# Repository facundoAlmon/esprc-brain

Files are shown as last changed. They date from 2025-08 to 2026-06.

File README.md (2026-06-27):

<div align="right">
<span>Español | <a href="README.en.md">English</a></span>
</div>

# 🚗 ESP-RC Brain: El Cerebro de Código Abierto para tu Coche RC

¡Te damos la bienvenida al repositorio de ESP-RC Brain! Este proyecto es el cerebro de un coche a radiocontrol inteligente, construido sobre un potente microcontrolador ESP32. Aquí encontrarás todo lo necesario para dar vida a tu propio vehículo: el firmware, los modelos 3D y una increíble aplicación web para que tomes el control desde cualquier navegador.

Este no es solo un coche a RC, es una plataforma abierta para que puedas experimentar, aprender y, sobre todo, ¡divertirte a lo grande!

¿Querés ver lo que ve el coche? Este proyecto tiene un módulo de cámara FPV complementario: **[esprc-cam](https://github.com/facundoAlmon/esprc-cam)**, un firmware para el módulo AI-Thinker ESP32-CAM que transmite video en vivo directamente a la webapp del brain.

## 🎬 Galería del Proyecto

### Videos

<p align="center">
<a href="https://www.youtube.com/watch?v=_Qa1ab6sNVU">
Demostracion de funcionamiento y control
</a>
<a href="https://www.youtube.com/watch?v=7CDSC2cwirc">
Control del auto con joystick de PS4
</a>
</p>

### Imágenes

<p align="center">
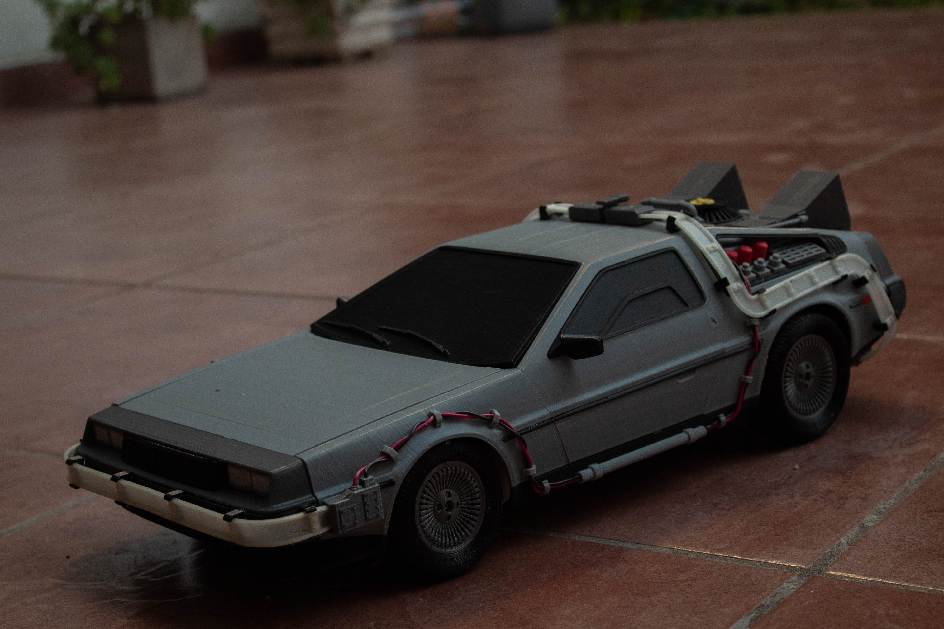
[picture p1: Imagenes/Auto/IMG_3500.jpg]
  
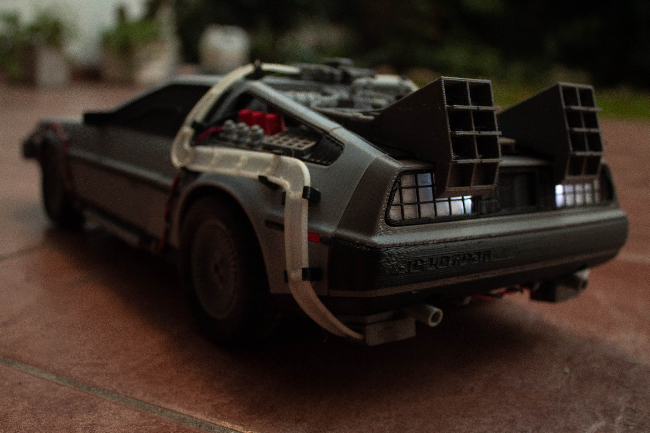
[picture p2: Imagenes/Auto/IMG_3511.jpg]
  
</p>
<p align="center">
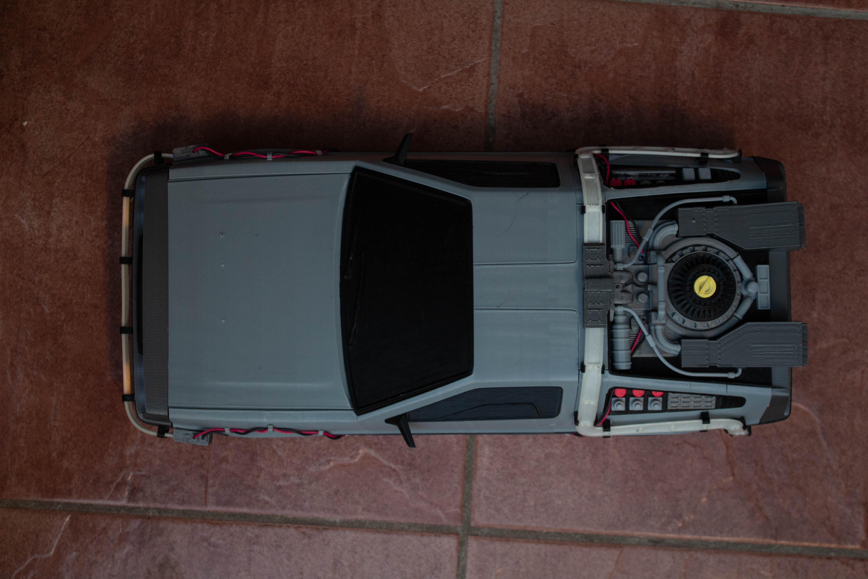
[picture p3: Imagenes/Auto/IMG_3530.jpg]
  
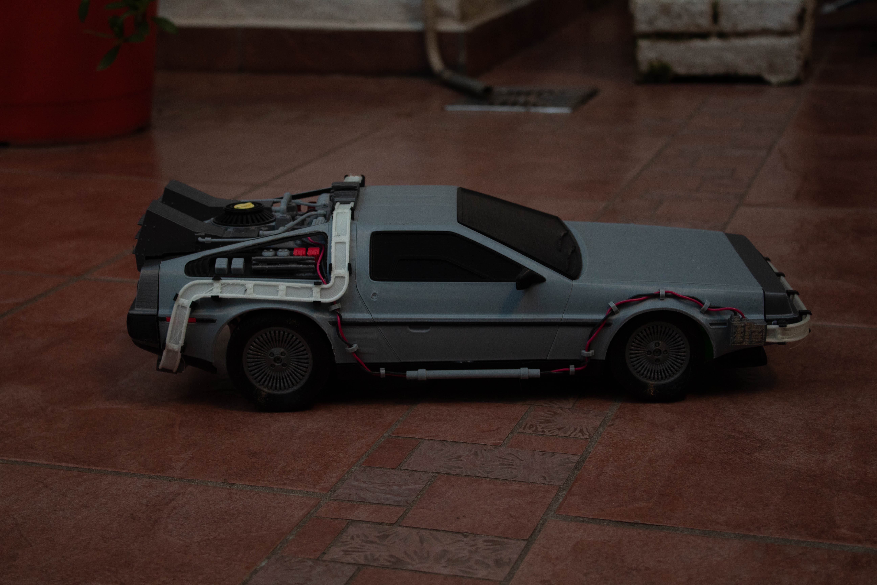
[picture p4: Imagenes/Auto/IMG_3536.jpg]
  
</p>
<p align="center">
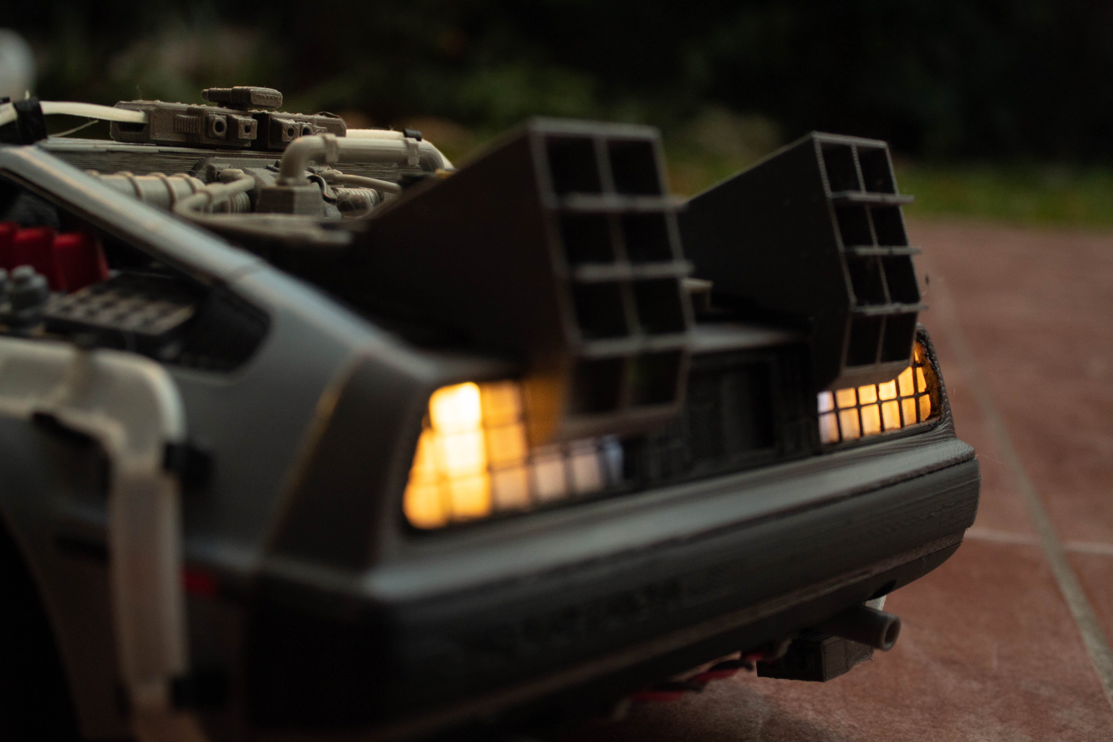
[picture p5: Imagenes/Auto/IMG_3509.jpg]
  
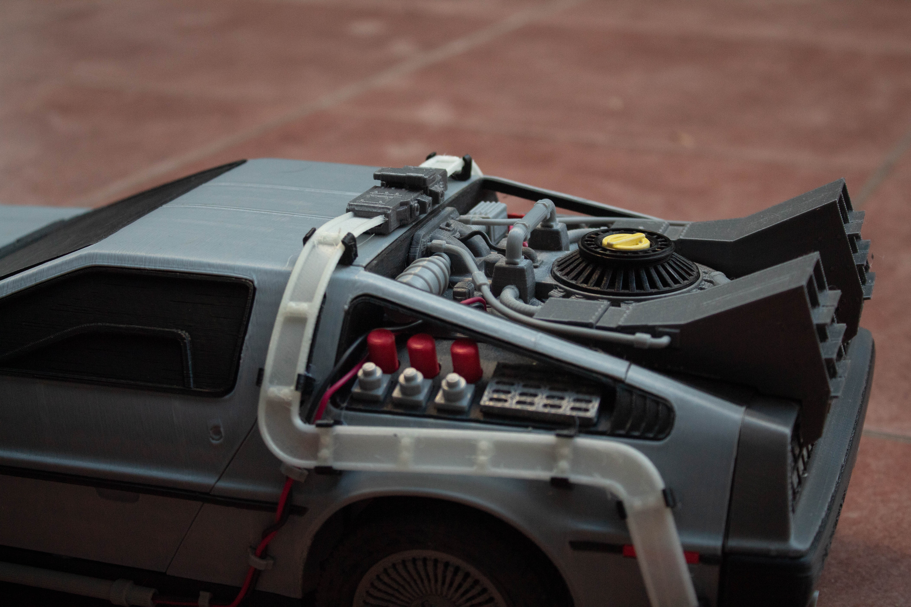
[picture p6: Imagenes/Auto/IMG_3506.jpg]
  
</p>
<p align="center">
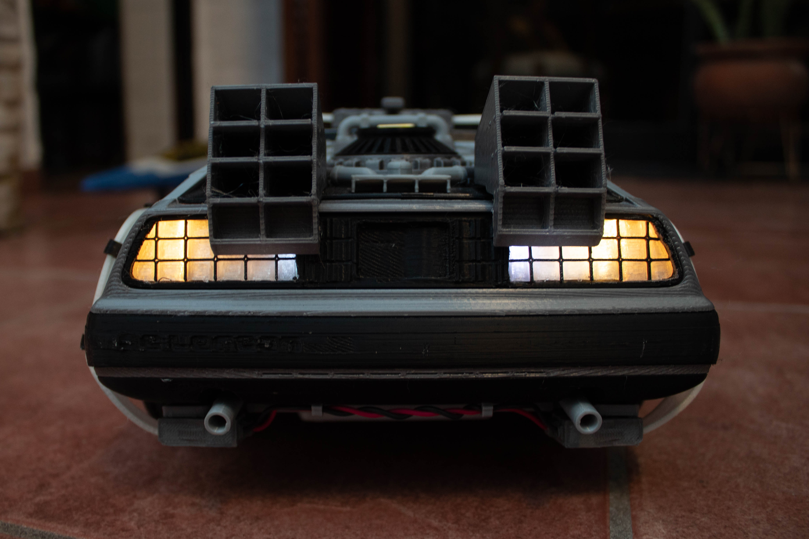
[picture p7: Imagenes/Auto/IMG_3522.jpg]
  
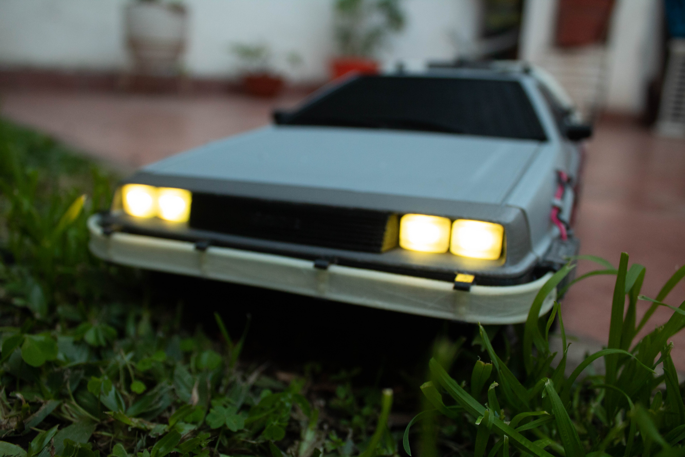
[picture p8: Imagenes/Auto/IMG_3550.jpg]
  
</p>
<p align="center">
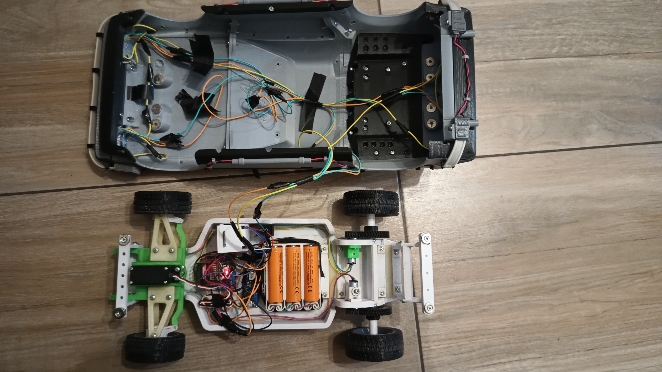
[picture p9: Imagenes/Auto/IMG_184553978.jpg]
  
  
</p>

## ✨ Características Principales

-   **Control Total y Flexible:**
    -   **Bluetooth:** Conecta un gamepad Xbox Series X/S o un mando HID estándar genérico vía Bluetooth y conduce con precisión. El stack BT es 100% nativo de ESP-IDF (`esp_hid_host` + Bluedroid), sin dependencias externas. Funciona en **ESP32** (Classic BT + BLE) y **ESP32-C6** (BLE).
    -   **Wi-Fi:** Usa la aplicación web integrada para controlar cada aspecto del coche desde tu teléfono, tablet o PC.

-   **Modos de Conectividad:**
    -   **Access Point (AP):** El coche crea su propia red Wi-Fi para que te conectes directamente, ideal para usarlo en cualquier lugar.
    -   **Modo Cliente:** Conecta el coche a tu red Wi-Fi existente para mayor comodidad en casa.

-   **Programación de Movimientos:** ¡Convierte tu coche en un robot programable!
    -   **Editor de Secuencias:** Desde la pestaña "Programa", puedes crear secuencias de movimiento personalizadas. Añade pasos como "Avanzar", "Girar a la Derecha" o "Esperar" y ajusta la duración de cada uno en milisegundos.
    -   **Modo de Programación para Niños:** Una interfaz visual y súper simplificada donde los niños pueden arrastrar y soltar bloques de comandos (avanzar, retroceder, girar, tocar la bocina) para crear sus propios programas de forma fácil e intuitiva.
    -   **Grabación y Reproducción en Tiempo Real:**
        -   **Graba Maniobras:** Pulsa el botón de grabar en la interfaz y simplemente conduce. El sistema registrará cada uno de tus movimientos, ya sea que uses los joysticks virtuales o un gamepad Bluetooth.
        -   **Luz Indicadora:** Un LED en el coche parpadeará en rojo para indicar que la grabación está activa.
        -   **Guarda y Ejecuta:** Los programas grabados y los creados en el editor se pueden guardar en la memoria del ESP32, exportar/importar como archivos JSON, y ejecutar cuando quieras, especificando el número de repeticiones o en bucle infinito.

-   **Aplicación Web Completa e Intuitiva:**
    -   **Dos Estilos de Joystick:** Elige entre un joystick unificado o dos palancas separadas (estilo tanque).
    -   **Configuración en Tiempo Real:** Ajusta la velocidad máxima, la velocidad mínima de arranque, la alineación del servo, los límites de giro y más, ¡todo desde el navegador y al instante!
    -   **Control Avanzado de Luces LED:** Personaliza las luces de tu coche (WS2812B). Crea grupos de LEDs y asígnales funciones como luz de posición, freno, marcha atrás, intermitentes, luz de interior o neón (Underglow). La configuración se puede importar y exportar.
    -   **Gestión del Sistema:** Reinicia el ESP32 o restaura la configuración de fábrica con un solo clic.

-   **⚙️ Motor de tracción DC o Brushless (ESC):** Elegí desde la webapp entre un **motor DC** (vía driver L298N) o un **motor brushless con ESC** (ej. Spektrum SPMXSM1300 + SPMXSE1085), sin recompilar. En modo ESC el firmware genera la señal PWM tipo servo, automatiza la secuencia de reversa (*freno → neutral → reversa*), incluye un **asistente de calibración** del ESC y permite ajustar velocidades (avance/reversa independientes), umbral de arranque, inversión de sentido, tiempos de reversa y un **modo crawl** para andar más lento que el mínimo del motor. También hay un **botón de freno** dedicado y umbrales configurables para el gamepad Bluetooth.

-   **🔌 Pines GPIO configurables:** Todos los pines del hardware (motor, servos de dirección y cámara, tira LED) se pueden cambiar desde la webapp sin recompilar. La configuración se guarda en NVS y se aplica tras un reboot automático. El botón "Reset to Defaults" restaura los valores de fábrica según el chip compilado (ESP32 / ESP32-C6).

-   **Firmware Robusto y Abierto:** Escrito en C++ sobre el framework oficial de Espressif (ESP-IDF) **puro** — sin dependencias de Arduino, Bluepad32 ni BTstack. Binario de ~1.4 MB, 66% de la partición libre.

-   **📷 Visión FPV integrada (con [esprc-cam](https://github.com/facundoAlmon/esprc-cam)):** Agregá un módulo AI-Thinker ESP32-CAM y disfrutá de una vista en primera persona directamente en la webapp. La cámara se descubre automáticamente en la red local vía **mDNS** cada 30 segundos — sin configuración manual de IP. El stream MJPEG aparece en la pestaña **Cámara** al instante, con soporte para pantalla completa y ajuste de imagen en tiempo real.

-   **🎮 Vista FPV con control integrado:** La pestaña **FPV** combina el stream de la cámara, el joystick de conducción y el pad invisible de control pan/tilt en una sola pantalla optimizada para mobile landscape — ideal para conducir mirando lo que ve el coche. Incluye todos los controles de luces, grabación y servos en la misma vista.

-   **🎥 Grabación de video desde la webapp:** Grabá el stream de la cámara directamente desde el navegador sin necesidad de firmware adicional. El sistema toma el control de la conexión MJPEG mientras graba, renderiza los frames en un canvas oculto y exporta un archivo `.webm` / `.mp4` al dispositivo.

-   **🎥 Servos de Cámara Pan/Tilt con movimiento suave:** Montá servos para apuntar la cámara y controlarlos desde el joystick virtual de la webapp o con el **stick derecho del gamepad Bluetooth**. El firmware actualiza los servos cada **15 ms** de forma continua (en lugar de solo al recibir un comando), eliminando el movimiento entrecortado. Dos modos de control: **Absoluto** (el stick mapea a una posición) y **Hold** (el stick controla la velocidad de movimiento y el servo mantiene la posición al soltar). Configuración completa desde la webapp: tipo de servo (SG90, S3003, custom), posición central, límites de giro, pulsos mínimo/máximo, inversión de eje, deadzone y saturación del stick.

## 📂 Estructura del Proyecto

Hemos organizado el repositorio de forma lógica para que encuentres todo fácilmente.

```
esprc-brain/
├── Firmware/
│   ├── main/             # Código fuente principal del ESP32 (C++).
│   │   ├── src/          # Archivos .cpp con la lógica de la aplicación.
│   │   └── include/      # Archivos de cabecera .h.
│   │
│   ├── webapp/           # Código fuente de la aplicación web (HTML, CSS, JS).
│   │
│   └── build/            # Carpeta de compilación (generada automáticamente).
│       └── esprc_brain.bin  # Binario para flashear/OTA
│
├── Models/               # Modelos 3D para imprimir las piezas del coche.
│   ├── SCADs/            # Archivos fuente de OpenSCAD (modificables).
│   ├── STLs/             # Archivos STL listos para imprimir.
│   └── README.MD         # Instrucciones sobre los modelos 3D.
│
├── README.md             # ¡Estás aquí!
└── LICENSE               # La licencia MIT de este proyecto.
```

## 🔩 Modelos 3D

Todos los modelos 3D utilizados para imprimir el chasis y la carrocería del coche se encuentran en la carpeta `Models`. Dentro de ella, encontrarás instrucciones más detalladas en el archivo `README.MD`.

- **[Ver detalles de los modelos 3D](./Models/README.MD)**

## 🚀 Primeros Pasos

¿Listo para construir? Aquí te explicamos cómo poner todo en marcha.

### Requisitos Previos

1.  **Hardware:** 
    - Un microcontrolador ESP32 (Se puede utilizar un ESP32 o un ESP32-C6).
    - LEDs WS2812 si se quieren usar las luces.
    - Para la tracción, una de estas dos opciones:
      - **Motor DC** + driver (probado con L298N), o
      - **Motor brushless + ESC** con señal tipo servo (probado con Spektrum SPMXSM1300 3300 KV + ESC SPMXSE1085). El ESC se conecta al mismo pin del motor; recordá el GND común.
    - Motor Servo (para la direccion)
    - *(Opcional)* 2 × Servo SG90 o compatible para montura pan/tilt de cámara
    - Alimentacion:
      - Actualmente estoy usando 3 baterias 18650 conectadas a un protector de bateria. Y un regulador Step-Down para bajar la tension a 5v para el ESP32 y el Motor Servo.
2.  **Software:**
    -   [ESP-IDF v6.0.1](https://docs.espressif.com/projects/esp-idf/en/v6.0.1/esp32/get-started/index.html): El entorno de desarrollo de Espressif (versión requerida: **v6.0.1**).
    -   [Node.js y npm](https://nodejs.org/): Para gestionar y compilar la aplicación web. (Solo necesario si se quiere modificar la webapp)
    -   [Git](https://git-scm.com/): Para clonar el repositorio.

### Preparar el Firmware (ESP32)

1.  **Clona el repositorio:**
    ```bash
    git clone https://gitlab.com/falmon/esprc-brain.git
    cd esprc-brain/Firmware
    ```

2.  **Activa el entorno ESP-IDF v6.0.1** (necesario en cada nueva sesión de terminal):
    ```bash
    . /ruta/a/esp-idf-v6.0.1/export.sh
    ```
    > Si instalaste IDF con el instalador oficial, usa el script `export.sh` de tu instalación local.

3.  **Selecciona el target** (una sola vez por clon, o al cambiar de chip):
    ```bash
    idf.py set-target esp32c6   # o: set-target esp32
    ```

4.  **Configura el proyecto** (opcional):
    Abre el menú de configuración para ajustar parámetros específicos de tu hardware.
    ```bash
    idf.py menuconfig
    ```

5.  **Compila el firmware:**
    ```bash
    idf.py build
    ```

6.  **Flashea el ESP32:**
    Conecta tu ESP32 por USB y ejecuta el siguiente comando. Recuerda cambiar `/dev/ttyUSB0` por el puerto serie que corresponda en tu sistema.
    ```bash
    idf.py -p /dev/ttyUSB0 flash monitor
    ```
    Este comando flashea el firmware y abre una consola serie para que veas los mensajes de diagnóstico en tiempo real.

> **Nota:** Si es la primera vez que flasheas o cambiaste el target, asegúrate de eliminar el archivo `sdkconfig` antes de compilar para que se regenere limpio: `rm -f sdkconfig`

### Desarrollo de la WebApp (Opcional)

Si quieres modificar la interfaz web, sigue estos pasos. La webapp usa **Gulp.js** para empaquetar todo el código (HTML, CSS, JS) en un único archivo que se integra en el firmware.

1.  **Navega a la carpeta de la webapp:**
    ```bash
    cd esprc-brain-c6/Firmware/webapp
    ```

2.  **Instala las dependencias:**
    ```bash
    npm install
    ```

3.  **Comandos útiles:**
    -   `npm run build` o `gulp`: Compila la webapp. Este comando empaqueta y minifica los archivos de `src/` y copia el `index.html` resultante en la carpeta `Firmware/main/`, listo para ser incluido en el firmware.
    -   `npm run serve`: Inicia un servidor local para probar la webapp en tu navegador sin necesidad de flashear el ESP32.
    -   `npm run clean`: Borra los archivos generados por la compilación.

> **Nota:** Después de modificar la webapp y compilarla con `npm run build`, debes volver a compilar y flashear el firmware del ESP32 para que los cambios surtan efecto en el coche.

## 🔧 Guía de Uso

### Primera Conexión

Por defecto, el ESP32 se inicia en **Modo Access Point (AP)**.

1.  **Conéctate a la red Wi-Fi:** En tu teléfono o PC, busca una red Wi-Fi llamada **"ESP-RC-CAR"** y conéctate a ella.
2.  **Abre la interfaz web:** Abre tu navegador y ve a la dirección [http://ecar.local](http://ecar.local) o [http://192.168.4.1](http://192.168.4.1).
3.  **¡A conducir!** Ya estás en la interfaz de control. Desde la pestaña **"Conexión"**, puedes cambiar al modo Cliente para que el coche se conecte a tu red Wi-Fi local.

### Conexion de Joystick Bluetooth

> Controllers soportados: **Xbox Series X/S** y mandos **HID estándar genéricos**. Funciona en ESP32 y ESP32-C6 (ambos vía BLE).

1. Poner el joystick en modo pairing
2. Asegurarse de tener el bluetooth activado en la seccion de **Configuración del Auto**
3. El ESP32 se conectara automaticamente al joystick

#### Layout
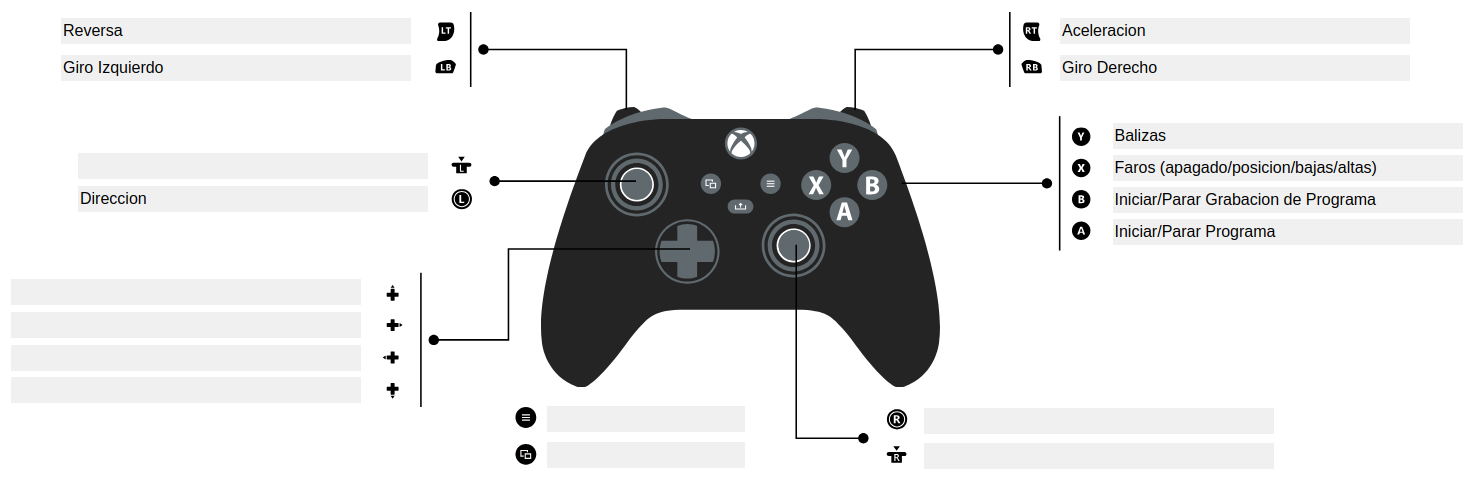
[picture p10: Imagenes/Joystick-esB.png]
  

## Guía Detallada de la Interfaz Web

La aplicación web te da un control granular sobre todas las funciones del coche. Se divide en las siguientes pestañas:

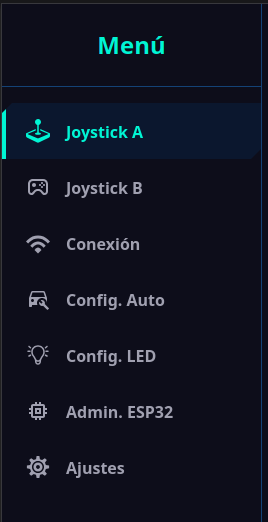
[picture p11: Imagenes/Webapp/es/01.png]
  

### 🕹️ Joystick A
<table>
<tr>
<td width="25%" valign="top">
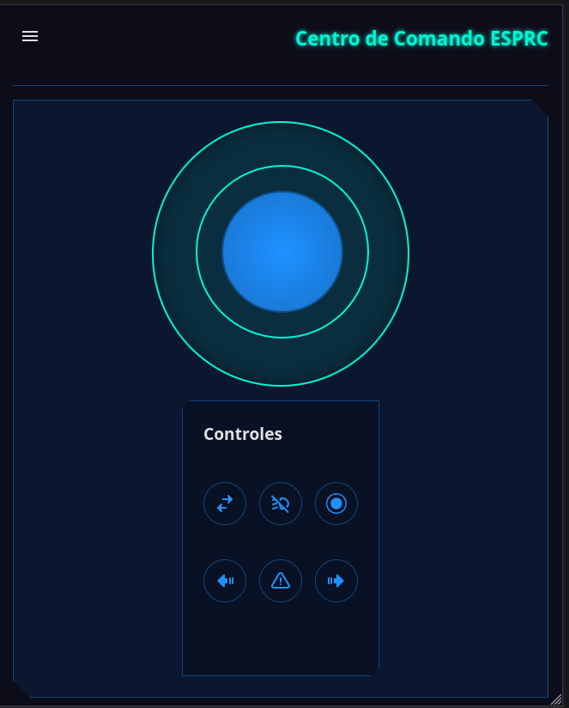
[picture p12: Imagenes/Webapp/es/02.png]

</td>
<td valign="top">
Este modo presenta un solo joystick virtual para un control unificado del vehículo.
<ul>
  <li><strong>Controles disponibles:</strong>
    <ul>
      <li><strong>Ubicación del Joystick:</strong> Puedes cambiar la posición del control en la pantalla para mayor comodidad.</li>
      <li><strong>Luces:</strong> Cicla entre los modos de faros (apagado, posición, bajas y altas).</li>
      <li><strong>Intermitentes:</strong> Activa las luces de giro izquierda y derecha.</li>
      <li><strong>Balizas:</strong> Activa las luces de emergencia.</li>
      <li><strong>Grabar:</strong> Comienza la grabacion (Los leds del grupo "LUZ GRABACION" parpadean cuando la grabacion esta activa).</li>
    </ul>
  </li>
</ul>
</td>
</tr>
</table>

### 🕹️🕹️ Joystick B
<table width="100%">
<tr>
<td width="40%" valign="top">
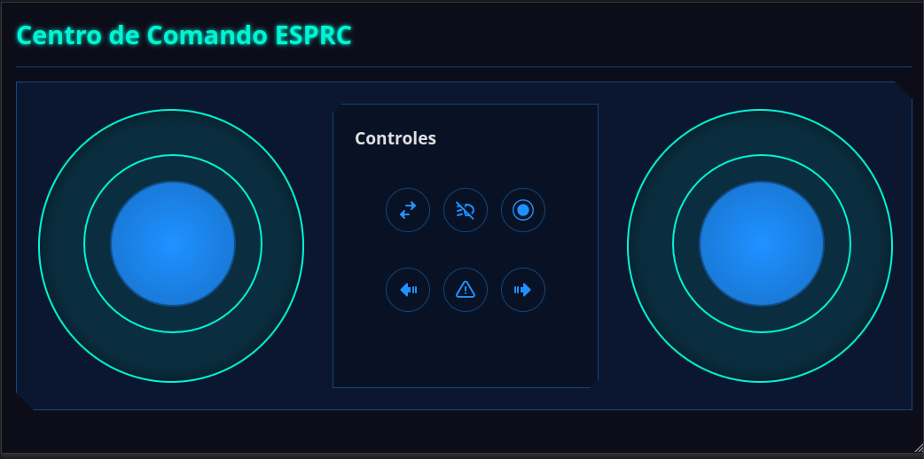
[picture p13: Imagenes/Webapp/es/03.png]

</td>
<td valign="top">
Este modo ofrece dos joysticks virtuales para un manejo independiente de la aceleración y la dirección, similar a un tanque.
<ul>
  <li><strong>Controles disponibles:</strong>
    <ul>
      <li><strong>Joystick de Dirección:</strong> Controla el servo de giro.</li>
      <li><strong>Joystick de Aceleración:</strong> Controla la velocidad y el sentido de los motores.</li>
      <li><strong>Invertir Joysticks:</strong> Intercambia la posición de los joysticks en pantalla.</li>
      <li><strong>Controles de Luces:</strong> Idénticos a los del Joystick A (faros, intermitentes, balizas).</li>
      <li><strong>Grabar:</strong> Comienza la grabacion (Los leds del grupo "LUZ GRABACION" parpadean cuando la grabacion esta activa).</li>
    </ul>
  </li>
</ul>
</td>
</tr>
</table>

### 📷 Cámara
<table width="100%">
<tr>
<td valign="top">
Esta pestaña muestra el video en vivo del módulo <strong><a href="https://github.com/facundoAlmon/esprc-cam">esprc-cam</a></strong> si hay una cámara disponible en la red.
<ul>
  <li><strong>Stream automático:</strong> Al abrir la webapp, el brain consulta la API y conecta el stream MJPEG automáticamente si la cámara fue descubierta vía mDNS.</li>
  <li><strong>Pantalla completa:</strong> Botón para ver el video en pantalla completa. El stream se mueve al overlay sin crear una segunda conexión.</li>
  <li><strong>Configuración de cámara:</strong> Ajustá resolución, calidad JPEG, brillo, contraste, saturación, espejo, volteo y parámetros avanzados del sensor OV2640 directamente desde esta pestaña.</li>
  <li><strong>Estadísticas FPS:</strong> Muestra los cuadros por segundo en tiempo real cuando las estadísticas están habilitadas en la cámara.</li>
</ul>
<blockquote>Requiere tener flasheado y encendido el módulo <strong><a href="https://github.com/facundoAlmon/esprc-cam">esprc-cam</a></strong> en la misma red Wi-Fi que el brain. La IP se guarda automáticamente en la memoria NVS del brain para reconexiones instantáneas.</blockquote>
</td>
</tr>
</table>

### 🎮 FPV

Vista inmersiva que combina el stream de la cámara con todos los controles en una sola pantalla, pensada para conducción en primera persona desde el celular en landscape.

- **Stream + control unificado:** El video de la cámara ocupa toda la pantalla y el joystick de conducción se superpone sobre él. Si los servos pan/tilt están habilitados, un pad táctil invisible sobre la imagen permite apuntar la cámara sin ocultar la vista.
- **Controles de luces y servos:** Botones de faros, intermitentes, balizas, mantener posición de cámara y centrar cámara accesibles lateralmente.
- **Grabación de video:** Botón de grabación que captura el stream MJPEG y descarga un archivo `.webm`/`.mp4` al dispositivo, sin ningún cambio en el firmware de la cámara.
- **Pantalla completa:** Botón para entrar en modo fullscreen.

> La pestaña FPV comparte la misma conexión MJPEG que la pestaña Cámara — el elemento `<img>` se mueve en el DOM sin abrir una segunda conexión al stream.

### 👨‍💻 Programa
<table width="100%">
<tr>
<td width="40%" valign="top">
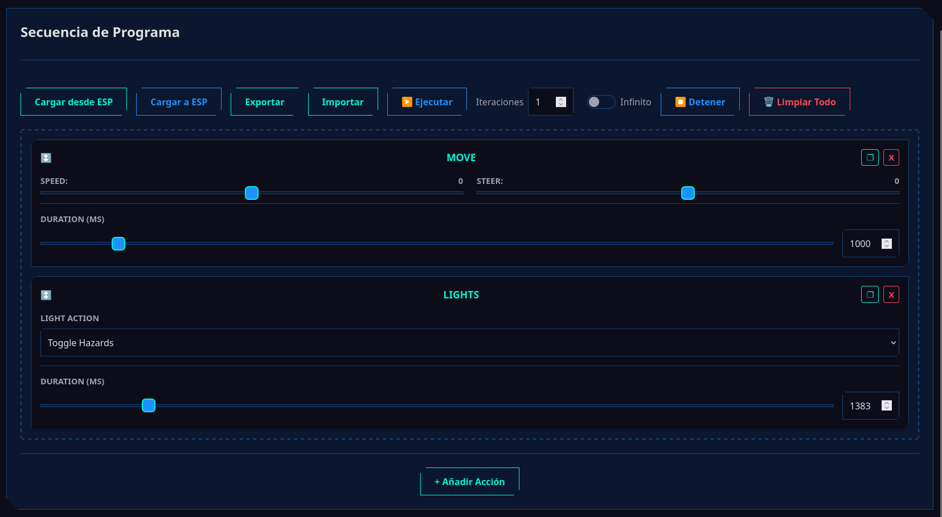
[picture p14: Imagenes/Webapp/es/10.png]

</td>
<td valign="top">
Esta pestaña convierte el coche en un robot programable. Aquí puedes crear, guardar y ejecutar secuencias de movimientos.
<ul>
  <li><strong>Controles del Programa:</strong>
    <ul>
      <li><strong>Cargar/Subir:</strong> Carga un programa desde la memoria del ESP32 o sube el que has creado para guardarlo.</li>
      <li><strong>Exportar/Importar:</strong> Guarda tu programa en un archivo JSON en tu dispositivo o importa uno que ya tengas.</li>
      <li><strong>Ejecutar/Detener:</strong> Inicia o para la ejecución de la secuencia.</li>
      <li><strong>Iteraciones:</strong> Define cuántas veces se repetirá el programa, o márcalo como infinito.</li>
    </ul>
  </li>
  <li><strong>Secuencia de Acciones:</strong>
    <ul>
      <li><strong>Añadir Acción:</strong> Agrega un nuevo paso a la secuencia.</li>
      <li><strong>Configurar Acción:</strong> Para cada paso, puedes elegir una dirección (avanzar, retroceder, etc.) y establecer una duración en milisegundos.</li>
      <li><strong>Ordenar y Eliminar:</strong> Arrastra las acciones para cambiar su orden o elimínalas individualmente.</li>
    </ul>
  </li>
</ul>
</td>
</tr>
</table>

### 🧒 Modo Niños
<table width="100%">
<tr>
<td width="40%" valign="top">
<!-- IMAGEN DE LA PESTAÑA MODO NIÑOS -->
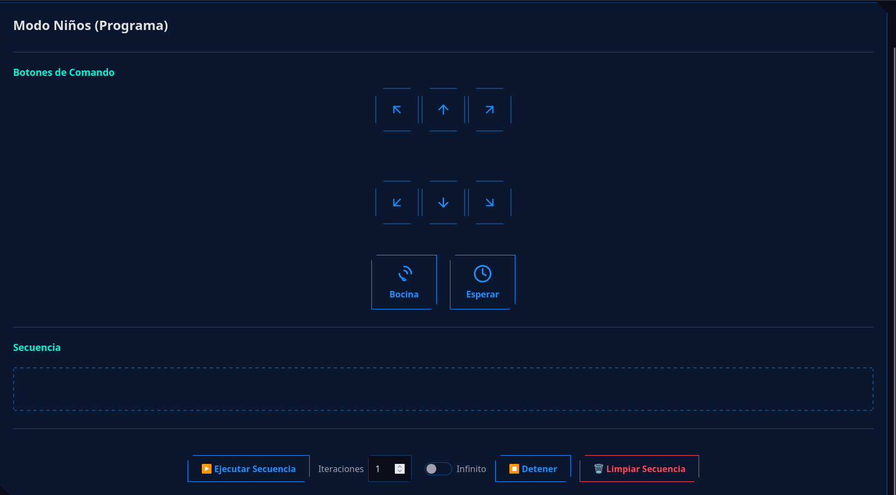
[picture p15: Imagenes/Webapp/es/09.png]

</td>
<td valign="top">
Una interfaz simplificada y visual diseñada para que los niños aprendan los fundamentos de la programación por bloques.
<ul>
  <li><strong>Paleta de Comandos:</strong>
    <ul>
      <li><strong>Botones Grandes:</strong> En lugar de un editor complejo, hay botones grandes para cada acción (avanzar, girar, retroceder, tocar bocina, esperar).</li>
      <li><strong>Construcción de Secuencia:</strong> Cada vez que se presiona un botón de comando, este se añade a la secuencia visual en la parte inferior.</li>
    </ul>
  </li>
  <li><strong>Ejecución de la Secuencia:</strong>
    <ul>
      <li>Los controles son sencillos: Ejecutar, Detener y Limpiar todo.</li>
      <li>También permite definir el número de repeticiones o un bucle infinito, igual que en el modo avanzado.</li>
    </ul>
  </li>
</ul>
</td>
</tr>
</table>

### 📡 Conexión
<table width="100%">
<tr>
<td width="40%" valign="top">
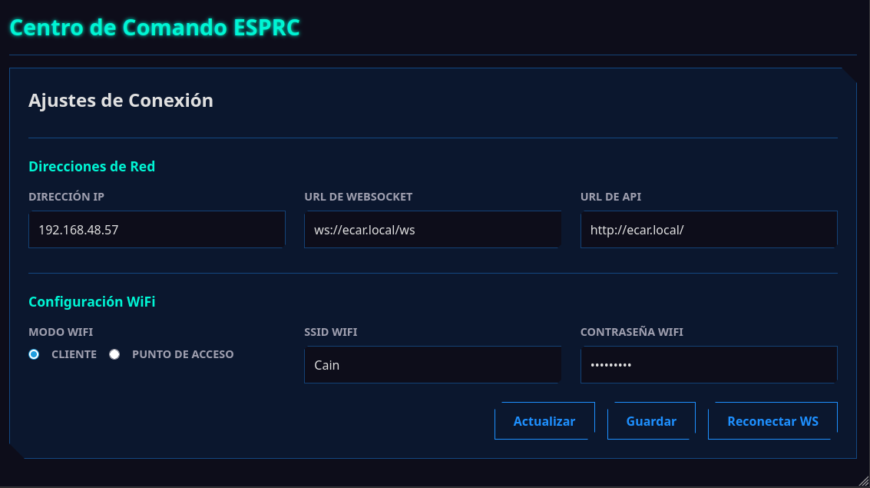
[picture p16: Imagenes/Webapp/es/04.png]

</td>
<td valign="top">
Aquí puedes configurar todo lo relacionado con la conectividad del ESP32.
<ul>
  <li><strong>Direcciones de Red:</strong>
    <ul>
      <li><strong>Dirección IP:</strong> Muestra la IP actual del ESP32.</li>
      <li><strong>URL de WebSocket:</strong> Dirección para la comunicación en tiempo real (control de movimiento). Puedes cambiarla para desarrollo local sin necesidad de guardar. Requiere pulsar `Reconectar Websocket`.</li>
      <li><strong>URL de API:</strong> Dirección para comandos y configuraciones. También se puede cambiar para desarrollo local.</li>
    </ul>
  </li>
  <li><strong>Configuración Wi-Fi:</strong>
    <ul>
      <li><strong>Modo Wi-Fi:</strong> Elige cómo se conecta el ESP32.
        <ul>
          <li><strong>Punto de Acceso (AP):</strong> El ESP32 crea su propia red Wi-Fi. Ideal para uso en exteriores.</li>
          <li><strong>Cliente:</strong> El ESP32 se conecta a una red Wi-Fi existente.</li>
        </ul>
      </li>
    </ul>
  </li>
  <li><strong>Acciones:</strong>
    <ul>
      <li><strong>Actualizar:</strong> Obtiene la configuración actual desde el ESP32.</li>
      <li><strong>Guardar:</strong> Almacena los cambios de configuración en el ESP32.</li>
      <li><strong>Reconectar Websocket:</strong> Reinicia la conexión de control en tiempo real.</li>
    </ul>
  </li>
</ul>
</td>
</tr>
</table>

### 🚗 Configuración del Auto
<table width="100%">
<tr>
<td width="40%" valign="top">
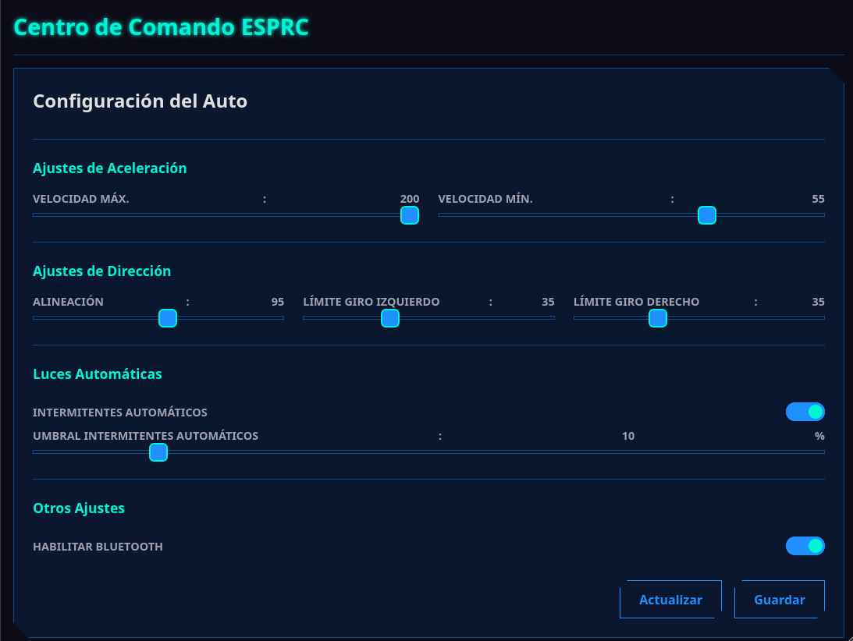
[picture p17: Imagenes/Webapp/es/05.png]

</td>
<td valign="top">
En esta sección se ajustan los parámetros físicos del coche.
<ul>
  <li><strong>Ajustes de Aceleración:</strong>
    <ul>
      <li><strong>Tipo de Motor:</strong> Elegí entre <strong>Motor DC (L298N)</strong> o <strong>Brushless + ESC</strong> (ej. Spektrum SPMXSM1300 + ESC SPMXSE1085). Cambiar el tipo reinicia el ESP automáticamente porque reconfigura el periférico del pin del motor.</li>
      <li><strong>Velocidad Máxima / Mínima:</strong> Limita la potencia máxima y define el mínimo para que el motor empiece a moverse. En modo ESC, la <strong>Velocidad Mín. (arranque)</strong> es clave: como un brushless sensorless no gira por debajo de cierto umbral, conviene ponerla en ese umbral (~100) para que el auto se mueva apenas tocás el stick.</li>
    </ul>
  </li>
  <li><strong>Motor Brushless + ESC</strong> (solo en modo ESC):
    <ul>
      <li><strong>Señal:</strong> El ESC se controla con una señal PWM tipo servo (1000–2000 µs, neutral 1500) por el <strong>mismo pin del motor</strong> (no hace falta un pin nuevo); el GND debe ser común entre ESC y ESP.</li>
      <li><strong>Velocidad Máx. Reversa:</strong> Límite de velocidad de reversa independiente del de avance.</li>
      <li><strong>Invertir sentido:</strong> Toggle para invertir adelante/reversa por software. <em>(Lo ideal para corregir el sentido físico es intercambiar 2 de los 3 cables del motor brushless o el Motor Rotation del ESC.)</em></li>
      <li><strong>Tiempos de reversa:</strong> Los ESC de auto exigen frenar antes de invertir. El firmware automatiza la secuencia <em>freno → neutral → reversa</em> para que "tirar atrás" termine en reversa sin soltar y reapretar. Los tiempos de <strong>freno</strong> y <strong>rearme</strong> son configurables (0 = reversa casi instantánea). Si venís de reversa (sin avance en el medio), reentra directo sin repetir la secuencia.</li>
      <li><strong>Modo Crawl (baja velocidad):</strong> Para andar <em>más lento que el mínimo del motor</em>, pulsa el throttle ("patadas" cortas + huecos en neutral). Configurable: <strong>tiempo de patada</strong> y <strong>gap máximo</strong>. Es a tirones por naturaleza (sensorless), pero permite crawl real. Aplica a avance y reversa.</li>
      <li><strong>Calibración de pulsos (avanzado):</strong> Pulsos de reversa/neutral/avance en µs, y un <strong>asistente de calibración</strong> del ESC (Neutral → Acelerador máx → Freno máx, siguiendo el botón SET del ESC).</li>
    </ul>
  </li>
  <li><strong>Freno:</strong> Botón <strong>FRENO</strong> en cada vista de joystick (mantener presionado = frena). En ESC aplica freno por señal; en DC frena activamente el L298N.</li>
  <li><strong>Ajustes de Dirección:</strong>
    <ul>
      <li><strong>Alineación:</strong> Calibra el punto central del servo de dirección.</li>
      <li><strong>Límite Giro Izquierdo:</strong> Establece el ángulo máximo de giro a la izquierda.</li>
      <li><strong>Límite Giro Derecho:</strong> Establece el ángulo máximo de giro a la derecha.</li>
    </ul>
  </li>
  <li><strong>Ajustes de Luces Automáticas:</strong>
    <ul>
      <li><strong>Activar Intermitentes Automáticos:</strong> Activa luces de giro automaticas.</li>
      <li><strong>Umbral Intermitentes Automáticos:</strong> Umbral para activacion de luces de giro.</li>
    </ul>
  </li>
  <li><strong>Bluetooth:</strong>
    <ul>
      <li><strong>Habilitar Bluetooth:</strong> Activa el modo de emparejamiento para conectar un nuevo joystick.</li>
      <li><strong>¡Atención!</strong> El Bluetooth se deshabilita por defecto al iniciar en modo AP para evitar conflictos.</li>
    </ul>
  </li>
  <li><strong>Gamepad Bluetooth (umbrales):</strong>
    <ul>
      <li><strong>Zona muerta acelerador/freno</strong> y <strong>Zona muerta dirección:</strong> Definen a partir de qué punto el gatillo y el stick del mando empiezan a actuar. Útil para mandos con drift o cruce entre ejes.</li>
    </ul>
  </li>
  <li><strong>Servos de Cámara (Pan/Tilt):</strong>
    <ul>
      <li><strong>Habilitar servos:</strong> Activa los dos canales LEDC adicionales para la montura pan/tilt.</li>
      <li><strong>Control con gamepad:</strong> Mapea el stick derecho del gamepad a los servos.</li>
      <li><strong>Botones de gamepad:</strong> <strong>RS click</strong> (stick derecho) centra la cámara al instante. <strong>Select/View</strong> alterna el Modo Hold desde el mando (persiste entre reinicios).</li>
      <li><strong>Modo Hold:</strong> El stick controla la velocidad de giro en lugar de la posición directa — el servo mantiene su posición al soltar el stick. Velocidad configurable en °/s.</li>
      <li><strong>Tipo de servo:</strong> Presets para SG90, S3003 o custom (pulso mínimo/máximo configurable).</li>
      <li><strong>Calibración:</strong> Posición central, límites de giro por eje e inversión de cada eje.</li>
      <li><strong>Deadzone / Saturación:</strong> Ajuste fino del comportamiento del stick.</li>
    </ul>
  </li>
</ul>
</td>
</tr>
</table>

### 💡 Configuración LED
<table width="100%">
<tr>
<td width="40%" valign="top">
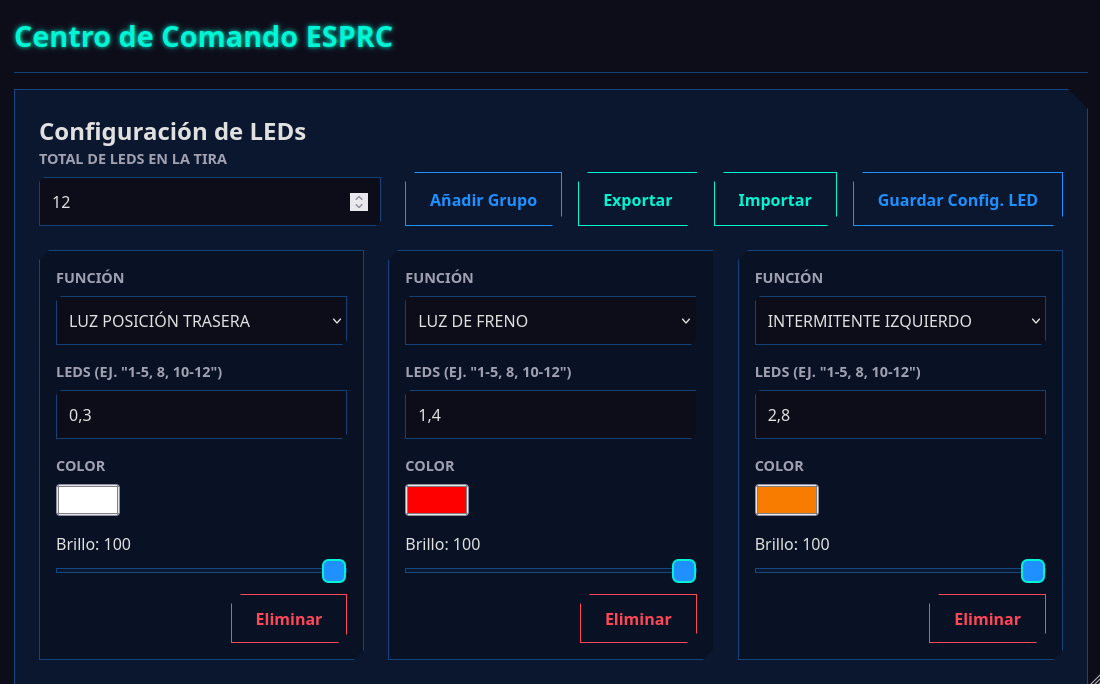
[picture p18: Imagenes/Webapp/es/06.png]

</td>
<td valign="top">
Personaliza el sistema de iluminación de tu coche. Se requieren LEDs direccionables (tipo WS2812B).
<ul>
  <li><strong>Definición de LEDs:</strong>
    <ul>
      <li>Primero, especifica la <strong>cantidad total de LEDs</strong> conectados en serie.</li>
      <li>Luego, crea <strong>grupos de LEDs</strong> asignándoles una función. Puedes definir los LEDs de un grupo con números separados por comas (ej: `0,1,5`) o rangos (ej: `6-9`), o una combinación (ej: `0,6-7,9-10,12`).</li>
    </ul>
  </li>
  <li><strong>Funciones de los Grupos:</strong>
  Para cada grupo, puedes definir la función, el color y el brillo.
    <ul>
      <li>`LUZ POSICION FRONTAL`: Faros delanteros.</li>
      <li>`LUZ POSICION TRASERA`: Faros traseros.</li>
      <li>`LUZ DE FRENO`</li>
      <li>`LUZ DE MARCHA ATRAS`</li>
      <li>`INTERMITENTE IZQUIERDO`</li>
      <li>`INTERMITENTE DERECHO`</li>
      <li>`LUZ INTERIOR`</li>
      <li>`LUZ BAJOS` (Efecto neón)</li>
      <li>`LUZ GRABACION`</li>
    </ul>
  </li>
  <li><strong>Comportamiento Actual:</strong>
    <ul>
      <li>Las luces de posición, interior y bajos se activan con el botón de faros y tienen 3 niveles de intensidad.</li>
      <li>Los intermitentes se activan tanto al girar como con las balizas.</li>
      <li>La luz de marcha atrás aún no está implementada.</li>
    </ul>
  </li>
</ul>
</td>
</tr>
</table>

### ⚙️ Administración ESP32
<table width="100%">
<tr>
<td width="25%" valign="top">
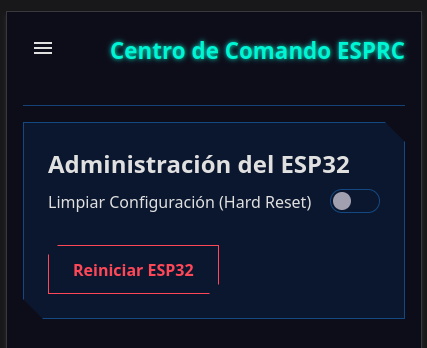
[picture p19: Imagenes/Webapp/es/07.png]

</td>
<td valign="top">
Tareas de mantenimiento del microcontrolador.
<ul>
  <li><strong>Reiniciar ESP32:</strong> Realiza un reinicio por software.</li>
  <li><strong>Limpiar Configuración (Hard Reset):</strong> Borra toda la configuración guardada y la restaura a los valores por defecto.</li>
  <li><strong>Configuración de Pines GPIO:</strong> Cambia los pines del motor, servos y tira LED desde el navegador sin recompilar. Los cambios se guardan en NVS y se aplican con un reboot automático. El botón <strong>Reset to Defaults</strong> restaura los pines de fábrica según el chip compilado (ESP32 / ESP32-C6).</li>
  <li><strong>Actualización de Firmware (OTA):</strong> Flasheá un nuevo <code>.bin</code> directamente desde el navegador sin cable USB.</li>
</ul>
</td>
</tr>
</table>

### 🔧 Ajustes
<table width="100%">
<tr>
<td width="25%" valign="top">
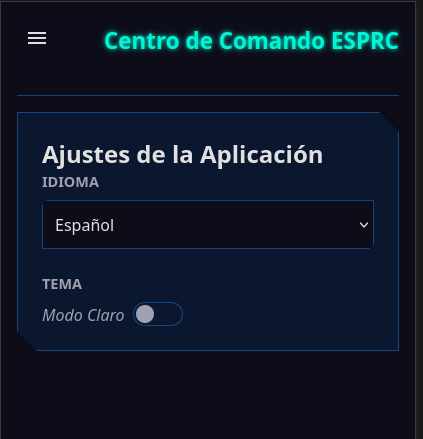
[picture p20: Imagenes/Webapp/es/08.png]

</td>
<td valign="top">
Configuraciones propias de la aplicación web.
<ul>
  <li><strong>Idioma:</strong> Cambia el idioma de la interfaz.</li>
  <li><strong>Apariencia:</strong> Elige entre el modo claro y el modo oscuro.</li>
</ul>
</td>
</tr>
</table>

## 🤝 ¿Quieres Contribuir?

¡Las contribuciones son el motor del código abierto y son más que bienvenidas! Si tienes una idea, has encontrado un error o quieres añadir una nueva funcionalidad, sigue estos pasos:

1.  Haz un **Fork** de este repositorio.
2.  Crea una nueva rama para tu funcionalidad (`git checkout -b feature/mi-idea-genial`).
3.  Realiza tus cambios y haz commit (`git commit -m 'Añado una nueva idea genial'`).
4.  Sube tu rama a tu fork (`git push origin feature/mi-idea-genial`).
5.  Abre un **Pull Request** para que podamos revisar tu aportación.

## 📝 Tareas Pendientes (ToDo)

-   [ ] Agregar un esquema del circuito electrónico.
-   [x] Función para exportar e importar la configuración completa del coche. (`/api/config/backup` y `/api/config/restore`)
-   [x] Soporte para cámara FPV vía **[esprc-cam](https://github.com/facundoAlmon/esprc-cam)** con auto-descubrimiento mDNS y control de imagen desde la webapp.
-   [x] Servos pan/tilt para apuntar la cámara, controlados desde el joystick virtual o el stick derecho del gamepad Bluetooth.
-   [x] Vista FPV con stream, joystick de conducción y pad pan/tilt superpuesto en una sola pantalla.
-   [x] Modo Hold para los servos de cámara (control de velocidad angular continua, movimiento suave cada 15 ms).
-   [x] Grabación de video MJPEG desde la webapp (sin firmware adicional), descarga como `.webm`/`.mp4`.
-   [x] Arbitraje BT/WS "el último input activo gana" — webapp y gamepad pueden coexistir sin conflictos. Frame neutro de webapp ya no pisa al gamepad BT; ventana de prioridad se cierra de inmediato al soltar el joystick virtual.
-   [x] Límites de cámara consistentes entre fuentes: joystick virtual, pad FPV y gamepad BT aplican los mismos límites configurados.
-   [x] Latencia FPV reducida: el pad táctil envía actualizaciones inmediatas (throttled a 30 ms) en lugar de esperar el ciclo de 100 ms.
-   [x] Botones de cámara en gamepad BT: **RS click** centra la cámara, **Select/View** alterna el modo hold (persiste entre reinicios).
-   [X] Pines configurables
-   [ ] Crear script de CICD

## 🙏 Agradecimientos

-   **[Duke Doks](https://dukedoks.com/):** Por crear y compartir los increíbles modelos 3D del [chasis](https://dukedoks.com/portfolio/guia-chasis-rc/) y la [carrocería](https://dukedoks.com/portfolio/guia-delorean-bttf/).
-   **[Benoît Blanchon](https://github.com/bblanchon):** Por la indispensable librería [ArduinoJson](https://github.com/bblanchon/ArduinoJson).
-   **[Ricardo Quesada](https://github.com/ricardoquesada):** Por [Bluepad32](https://github.com/ricardoquesada/bluepad32), que fue la base del soporte BT en versiones anteriores del proyecto.

## 📜 Licencia

Este proyecto está distribuido bajo la **Licencia MIT**. Esto significa que eres libre de usar, modificar y distribuir el código como quieras, siempre que mantengas el aviso de copyright original.

> El firmware utiliza exclusivamente componentes nativos de ESP-IDF y librerías bajo licencias permisivas (MIT/Apache 2.0). No hay dependencias con licencias restrictivas.

---
Hecho con ❤️, ☕ y muchos cables por [Facundo Almon](https://github.com/facundoAlmon).

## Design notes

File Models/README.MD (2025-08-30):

# Impresion 3D del auto
Para el chasis del auto elegí el chasis OpenRC de Duke Doks. El modelo es genial, solo requiere algunos tornillos M3 y tuercas para su ensamble. 
Lo imprimi en mi Ender 3 V2 usando PETG (Grillon3) para la mayoria de las partes y Simpliflex (Grillon3) para las partes flexibles:
- Link del modelo: https://www.thingiverse.com/thing:4892947
- Guia de ensamble: https://dukedoks.com/portfolio/guia-chasis-rc/

Las partes electrónicas NO son las del modelo, fueron reemplazadas por partes que pude conseguir en Argentina a un precio accesible (o recicladas) y adaptadas para utilizar el microcontrolador como "cerebro" del auto.

## Modificaciones del Modelos

Modifique algunas partes del modelo para adaptarla a los motores que decidi utilizar (2 Motores DC Pololu de 500 RPM). En particular modifique:
- "Rear_Frame_L.stl" para añadir las guias para el motor 
- "Gear_1.stl" para adaptarlo al eje del motor DC
- Cree el modelo "motorHoldPololu" para poder instalar los motores en las guias de la parte trasera
- Genere unos anillos para reemplazar los rulemanes de las ruedas (ya que no los pude conseguir). "fake_bear_back" y "fake_bear_front"

Al utilizar 2 motores traseros, sera necesario imprimir:
- 2x gearModPololu.stl
- 2x Gear_2.stl
- 2x Popolu_Adapter.stl

Si no conseguis los rulemanes tambien sera necesario imprimir los siguientes modelos para reemplazarlos:
- 2x "fake_bear_back.stl"
- 2x "fake_bear_front.stl"

## Guia de Ensamble

El resto del ensamble es tal cual lo indica la guiá del autor del modelo: https://dukedoks.com/portfolio/guia-chasis-rc/

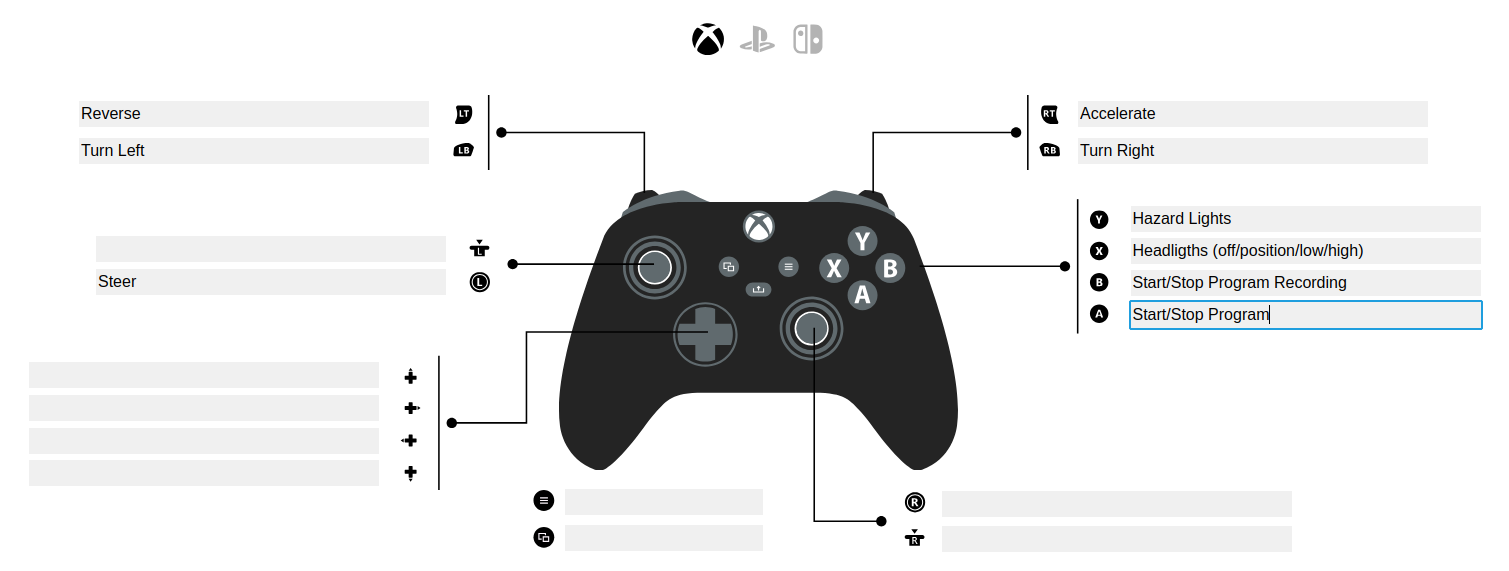
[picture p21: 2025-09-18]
Imagenes/Joystick-enB.png

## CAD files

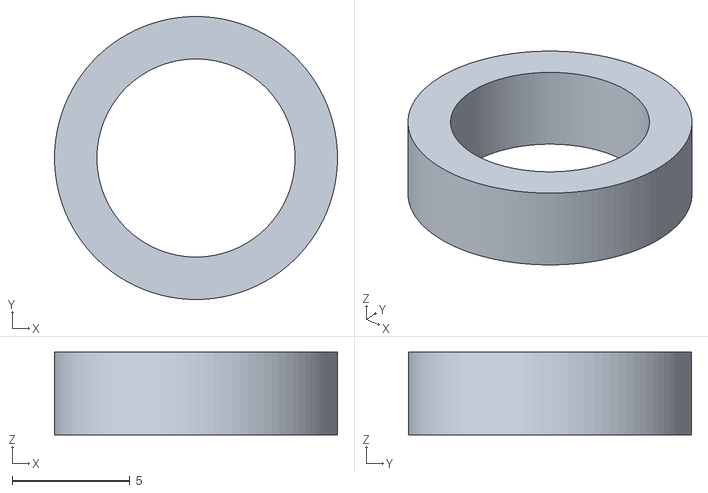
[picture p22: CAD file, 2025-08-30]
Models/STLs/fake_bear_front.stl
12.0 x 12.0 x 3.50

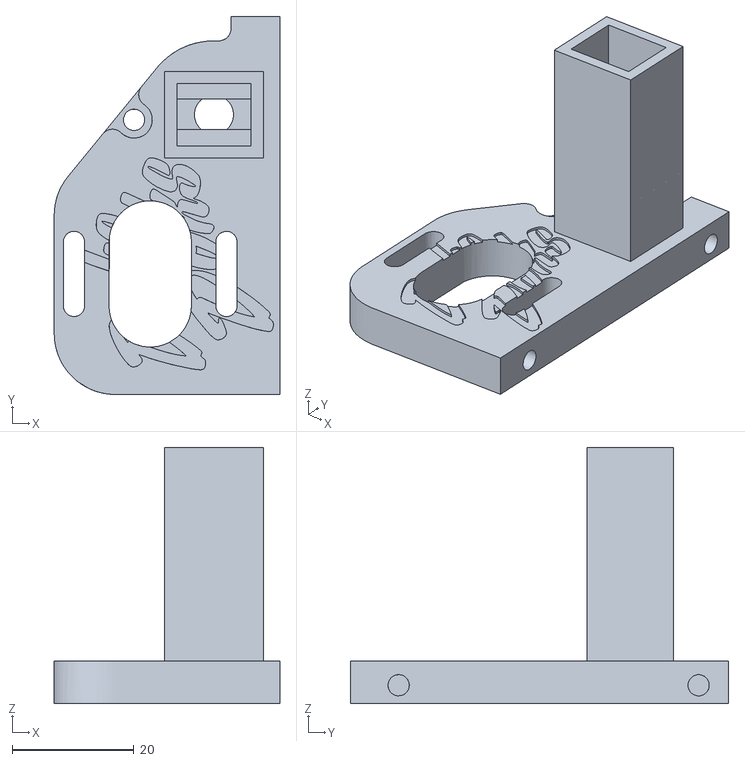
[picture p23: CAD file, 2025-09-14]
Models/V2/RearFrameLeftModV2.stl
37.0 x 62.0 x 42.0

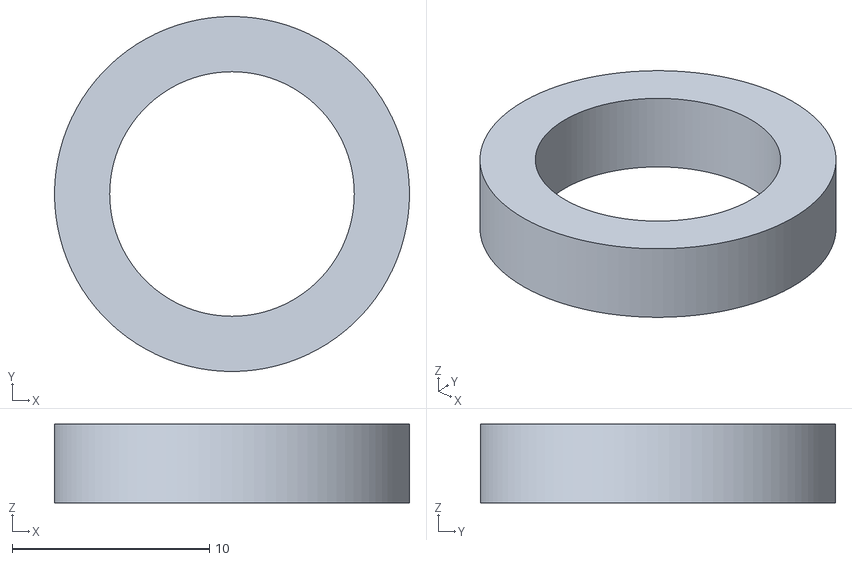
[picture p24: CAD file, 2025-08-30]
Models/STLs/fake_bear_back.stl
18.0 x 18.0 x 4.00

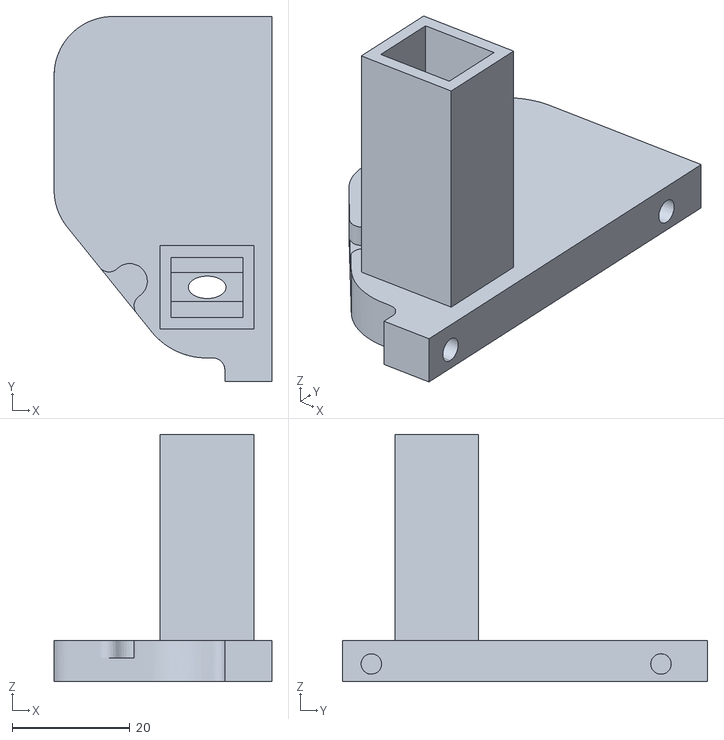
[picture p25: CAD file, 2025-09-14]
Models/V2/RearFrameRightModV2.stl
37.0 x 62.0 x 42.0

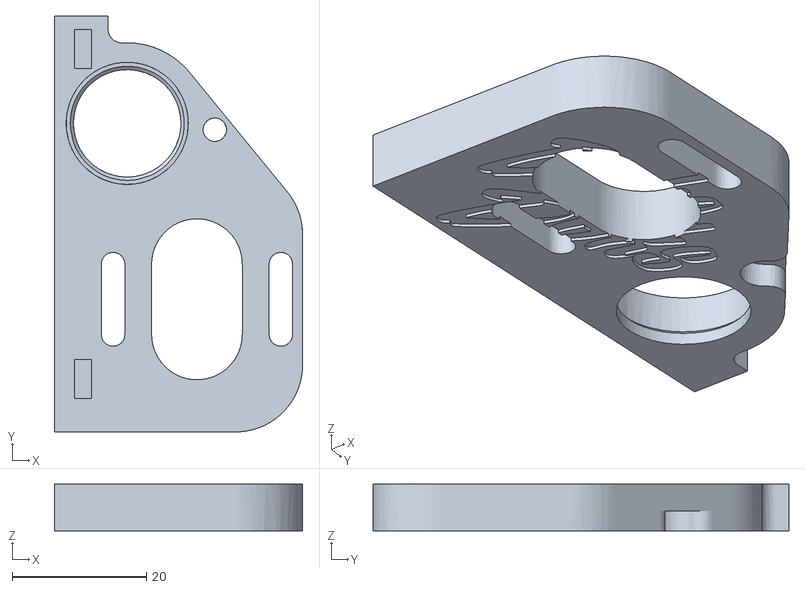
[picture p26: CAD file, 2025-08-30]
Models/STLs/RearFrameLeftMod.stl
37.0 x 62.0 x 7.00

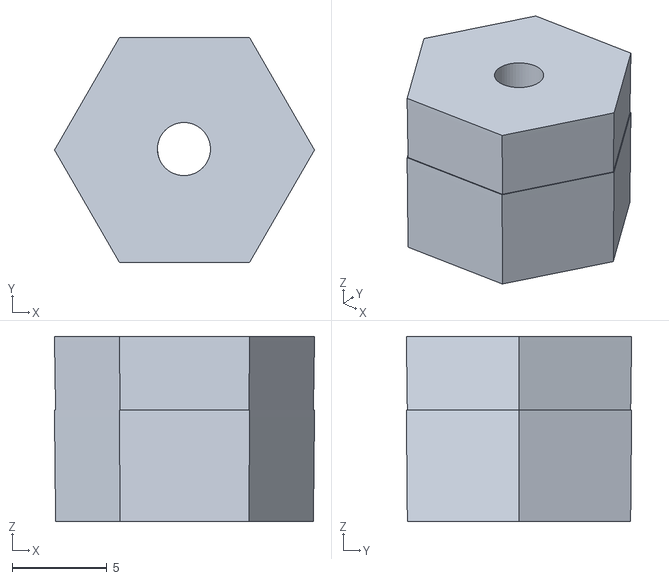
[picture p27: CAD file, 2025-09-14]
Models/V2/WheelAdapterModV2.stl
13.7 x 11.9 x 9.80

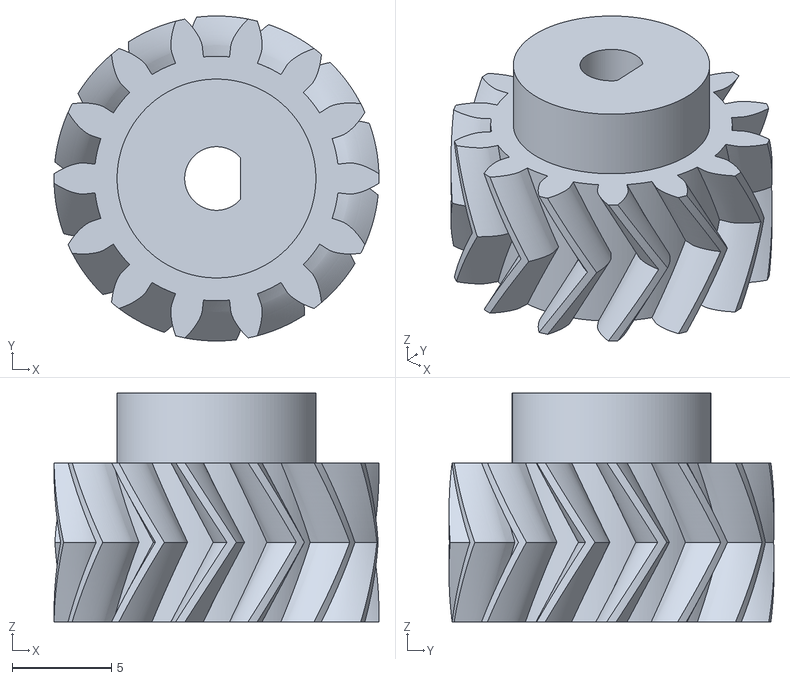
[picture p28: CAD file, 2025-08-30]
Models/STLs/gearModPololu.stl
16.3 x 16.3 x 11.5

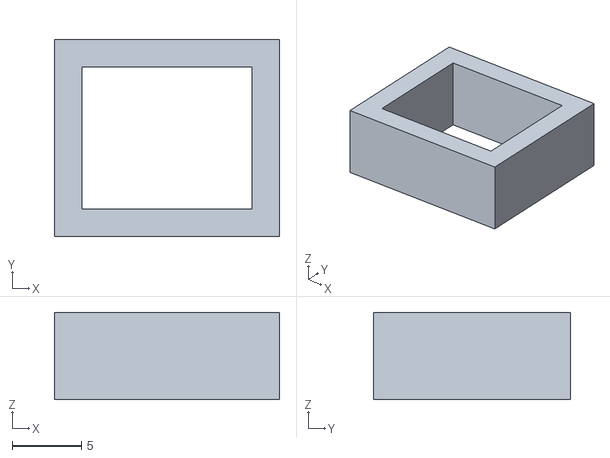
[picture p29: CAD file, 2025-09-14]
Models/V2/TestN20Fit.stl
16.2 x 14.2 x 6.30

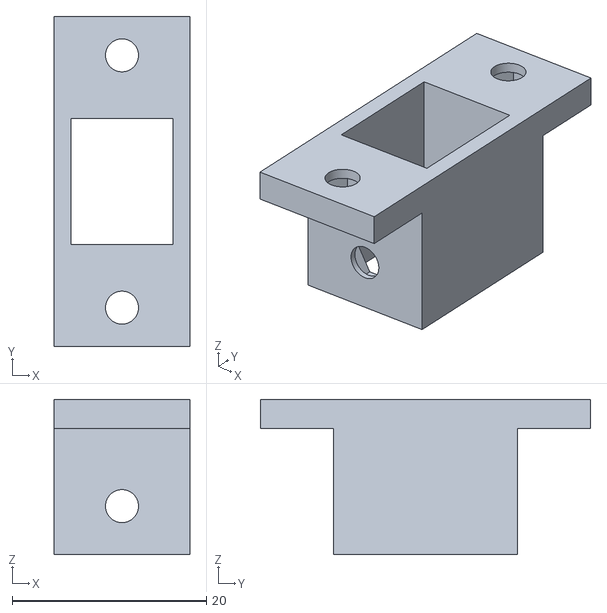
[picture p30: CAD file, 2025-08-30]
Models/STLs/motorHoldPololu.stl
14.0 x 34.0 x 16.0

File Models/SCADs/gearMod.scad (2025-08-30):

module gear(){
#import("/mnt/Black/Impresion3D/Modelos/Robotica/AutoRC/files/Gear_1.stl"); 
   import("G:\\Impresion3D\\Modelos\\Robotica\\AutoRC\\files\\Gear_1.stl"); 
    cylinder(r=3,h=11.5,$fn=100);
}

module eje_pololu(){
difference(){
translate ([0,0,0]) cylinder(r=3.2/2,h=20,$fn=100);

translate ([1.2,-1.50,-1]) cube([40,40,22]);
    
}
}

module gearMod() {
difference(){
gear();
eje_pololu();
}

}
gearMod();
//eje_pololu();

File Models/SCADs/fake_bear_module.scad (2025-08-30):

module fake_bear(diam_ext,diam_int,alt){
difference(){
    cylinder(r=diam_ext/2, h=alt,$fn=100);
    translate([0,0,-1])
        cylinder(r=diam_int/2, h=alt+2,$fn=100);
}
}

//Adelante (Chico)
fake_bear(12,8.4,3.5);

//Atras (Grande)
//fake_bear(18,,4);

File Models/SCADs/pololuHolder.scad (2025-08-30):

//pololu
//cube([10,12,23],true);

//LONG = 23-7 = 16 14

//cover
//cube([12,14,14],true);
diam_tuerca = 6.5;
diam_tornillo = 3.4;


difference(){
 cube([14,19,16],true);   
    cube([10.5,13,23],true);
    translate([0,20,-3]) rotate([90,0,0]) cylinder(r=diam_tornillo/2,h=40,$fn=100);
    translate([0,-6.4,-3]) rotate([90,0,0]) cylinder(r=diam_tuerca/2,h=2.5,$fn=6);
    translate([0,8.9,-3]) rotate([90,0,0]) cylinder(r=diam_tuerca/2,h=2.5,$fn=6);
    //translate([0,10,0]) cube([2.7,10,12],true);
    //translate([0,-10,0]) cube([2.7,10,12],true);
}


translate([0,0,6.5])
difference(){
cube([14,34,3],true);
    
    //cube([3,29,5],true);    
    
    translate([0,13,-2]) cylinder(r=diam_tuerca/2,h=2.5,$fn=6);
    translate([0,13,-2]) cylinder(r=diam_tornillo/2,h=50,$fn=100);
    
    
    translate([0,-13,-2]) cylinder(r=diam_tuerca/2,h=2.5,$fn=6);
    translate([0,-13,-2]) cylinder(r=diam_tornillo/2,h=50,$fn=100);
    
    cube([10.5,13,23],true);
    
    
}

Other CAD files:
Models/SCADs/RearFrameLeftMod.scad

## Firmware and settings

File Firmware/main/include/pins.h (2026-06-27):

#pragma once
#include "driver/gpio.h"
#include "driver/ledc.h"
#include "sdkconfig.h"

// LEDC channel assignments are fixed (only GPIO numbers are runtime-configurable).
#define STEER_SERVO_CHANNEL  LEDC_CHANNEL_2
#define PAN_SERVO_CHANNEL    LEDC_CHANNEL_3
#define TILT_SERVO_CHANNEL   LEDC_CHANNEL_4
#define ESC_CHANNEL          LEDC_CHANNEL_5  // Señal del ESC brushless (reusa pinMotorEn)

// Compile-time defaults — used as NVS fallback and for "reset to defaults".
#if defined(CONFIG_IDF_TARGET_ESP32C6)
  #define PIN_CHIP_TYPE        "esp32c6"
  #define PIN_LED_STRIP_DEFAULT   8
  #define PIN_MOTOR_EN_DEFAULT   19
  #define PIN_MOTOR_DIR1_DEFAULT 20
  #define PIN_MOTOR_DIR2_DEFAULT 21
  #define PIN_STEER_DEFAULT       7
  #define PIN_PAN_DEFAULT         4
  #define PIN_TILT_DEFAULT        5
#elif defined(CONFIG_IDF_TARGET_ESP32)
  #define PIN_CHIP_TYPE        "esp32"
  #define PIN_LED_STRIP_DEFAULT  16
  #define PIN_MOTOR_EN_DEFAULT   25
  #define PIN_MOTOR_DIR1_DEFAULT 32
  #define PIN_MOTOR_DIR2_DEFAULT 33
  #define PIN_STEER_DEFAULT      13
  #define PIN_PAN_DEFAULT        14
  #define PIN_TILT_DEFAULT       27
#else
  #error "Unsupported target. Please define pin defaults for your board in pins.h"
#endif

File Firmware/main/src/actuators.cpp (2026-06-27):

/**
 * @file actuators.cpp
 * @brief Implementación del control de actuadores (motor y servo).
 */
#include "actuators.h"
#include <cstring>
#include "esp_log.h"
#include "esp_timer.h"
#include "driver/mcpwm_prelude.h"
#include "driver/gpio.h"
#include "driver/ledc.h"
#include "pins.h"

#define SERVO_FREQ_HZ    50
#define SERVO_MIN_US     500
#define SERVO_MAX_US     2500
#define SERVO_MAX_ANGLE  180
#define SERVO_RES_BITS   LEDC_TIMER_14_BIT
#define SERVO_RES_MAX    ((1u << 14) - 1)
#define SERVO_PERIOD_US  (1000000 / SERVO_FREQ_HZ)
#define MOTOR_PERIOD_TICKS 50  // 1 MHz / 20 kHz

static mcpwm_timer_handle_t s_motor_timer = NULL;
static mcpwm_oper_handle_t  s_motor_oper  = NULL;
static mcpwm_cmpr_handle_t  s_motor_cmpr  = NULL;
static mcpwm_gen_handle_t   s_motor_gen   = NULL;

// Timestamp del último comando de calibración del ESC. El bloqueo de calibración
// se auto-libera tras este tiempo para que una calibración olvidada (sin "Finalizar")
// no deje el motor sin responder indefinidamente.
static int64_t s_esc_cal_last_us = 0;
#define ESC_CAL_TIMEOUT_US (60LL * 1000000LL)  // 60 s

// Secuencia automática de reversa para el ESC. Los ESC de auto interpretan el
// primer pulso de reversa como FRENO; sólo después de pasar por neutral el
// siguiente pulso de reversa es reversa real. updateEsc reproduce esa secuencia
// (FRENO→NEUTRAL→REVERSA) para que "tirar atrás" termine en reversa sin que el
// usuario tenga que soltar y volver a apretar.
enum EscPhase { ESC_PHASE_NEUTRAL, ESC_PHASE_FORWARD, ESC_PHASE_BRAKE, ESC_PHASE_REARM, ESC_PHASE_REVERSE };
static EscPhase s_esc_phase = ESC_PHASE_NEUTRAL;
static int64_t  s_esc_phase_us = 0;
// El ESC queda "cebado" para reversa tras reversar: mientras no se aplique avance,
// volver a pedir reversa (reversa→neutral→reversa) entra directo SIN repetir el baile
// freno→neutral. Sólo el avance resetea el cebado.
static bool s_esc_rev_primed = false;

// Modo crawl: pulsa el throttle (patada al umbral de arranque + gap en neutral) para
// promediar velocidades por debajo del mínimo continuo del motor.
static bool    s_crawl_on = false;
static int64_t s_crawl_us = 0;

// Togglea kick/gap según los tiempos. true = sacar la patada; false = neutral.
static bool crawl_kick_now(int64_t now, int64_t onUs, int64_t offUs) {
    if (s_crawl_on) { if (now - s_crawl_us >= onUs)  { s_crawl_on = false; s_crawl_us = now; } }
    else            { if (now - s_crawl_us >= offUs) { s_crawl_on = true;  s_crawl_us = now; } }
    return s_crawl_on;
}

// Gap (µs) para una velocidad pedida d en (0, escMinSpeed): más lento → más gap, capado.
static int64_t crawl_off_us(VehicleState* st, uint32_t d) {
    if (d == 0) return (int64_t)st->escCrawlMaxOffMs * 1000LL;
    int64_t off = (int64_t)st->escCrawlOnMs * (int64_t)(st->escMinSpeed - d) / (int64_t)d;
    int64_t cap = (int64_t)st->escCrawlMaxOffMs;
    return (off > cap ? cap : off) * 1000LL;
}
// Tiempos de freno/rearme configurables (state->escBrakeMs / escRearmMs, en ms).

static void servo_write_angle(int degrees) {
    uint32_t pulse_us = SERVO_MIN_US +
        (uint32_t)((uint32_t)degrees * (SERVO_MAX_US - SERVO_MIN_US) / SERVO_MAX_ANGLE);
    uint32_t duty = (uint32_t)((uint64_t)pulse_us * SERVO_RES_MAX / SERVO_PERIOD_US);
    ledc_set_duty(LEDC_LOW_SPEED_MODE, STEER_SERVO_CHANNEL, duty);
    ledc_update_duty(LEDC_LOW_SPEED_MODE, STEER_SERVO_CHANNEL);
}

// Emite un pulso (en microsegundos) por el canal LEDC del ESC. El ESC brushless
// usa el mismo timer LEDC de 50 Hz / 14-bit que los servos.
static void esc_write_us(uint32_t pulse_us) {
    uint32_t duty = (uint32_t)((uint64_t)pulse_us * SERVO_RES_MAX / SERVO_PERIOD_US);
    ledc_set_duty(LEDC_LOW_SPEED_MODE, ESC_CHANNEL, duty);
    ledc_update_duty(LEDC_LOW_SPEED_MODE, ESC_CHANNEL);
}

/**
 * @brief Configura e inicializa los pines y periféricos para los actuadores.
 */
void setupActuators(VehicleState* state) {
    // Timer LEDC compartido por todos los servos (y por el ESC): 50 Hz, 14-bit.
    ledc_timer_config_t servo_timer = {
        .speed_mode      = LEDC_LOW_SPEED_MODE,
        .duty_resolution = SERVO_RES_BITS,
        .timer_num       = LEDC_TIMER_0,
        .freq_hz         = SERVO_FREQ_HZ,
        .clk_cfg         = LEDC_AUTO_CLK,
    };
    ledc_timer_config(&servo_timer);

    // Servo de dirección vía LEDC directo (siempre).
    ledc_channel_config_t servo_ch = {
        .gpio_num   = (gpio_num_t)state->pinSteerServo,
        .speed_mode = LEDC_LOW_SPEED_MODE,
        .channel    = STEER_SERVO_CHANNEL,
        .intr_type  = LEDC_INTR_DISABLE,
        .timer_sel  = LEDC_TIMER_0,
        .duty       = 0,
        .hpoint     = 0,
    };
    ledc_channel_config(&servo_ch);

    if (state->motorType == 1) {
        // Motor brushless con ESC: señal PWM tipo servo (1000-2000 µs) por pinMotorEn.
        ledc_channel_config_t esc_ch = {
            .gpio_num   = (gpio_num_t)state->pinMotorEn,
            .speed_mode = LEDC_LOW_SPEED_MODE,
            .channel    = ESC_CHANNEL,
            .intr_type  = LEDC_INTR_DISABLE,
            .timer_sel  = LEDC_TIMER_0,
            .duty       = 0,
            .hpoint     = 0,
        };
        ledc_channel_config(&esc_ch);
        esc_write_us(state->escCenterUs);  // arma el ESC en neutral al arrancar
        ESP_LOGI("ESC", "Modo ESC brushless en GPIO %d (neutral=%u us, min=%u, max=%u)",
                 state->pinMotorEn, (unsigned)state->escCenterUs,
                 (unsigned)state->escMinUs, (unsigned)state->escMaxUs);
    } else {
        // Motor DC vía L298N: MCPWM a 20 kHz (API handle-based IDF v6.0+).
        mcpwm_timer_config_t timer_cfg = {
            .group_id      = 0,
            .clk_src       = MCPWM_TIMER_CLK_SRC_DEFAULT,
            .resolution_hz = 1000000,
            .count_mode    = MCPWM_TIMER_COUNT_MODE_UP,
            .period_ticks  = MOTOR_PERIOD_TICKS,
        };
        mcpwm_new_timer(&timer_cfg, &s_motor_timer);

        mcpwm_operator_config_t oper_cfg = { .group_id = 0 };
        mcpwm_new_operator(&oper_cfg, &s_motor_oper);
        mcpwm_operator_connect_timer(s_motor_oper, s_motor_timer);

        mcpwm_comparator_config_t cmpr_cfg = {};
        cmpr_cfg.flags.update_cmp_on_tez = true;
        mcpwm_new_comparator(s_motor_oper, &cmpr_cfg, &s_motor_cmpr);
        mcpwm_comparator_set_compare_value(s_motor_cmpr, 0);
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

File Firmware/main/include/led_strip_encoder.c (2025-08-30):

/*
 * SPDX-FileCopyrightText: 2021-2022 Espressif Systems (Shanghai) CO LTD
 *
 * SPDX-License-Identifier: Apache-2.0
 */

 #include "esp_check.h"
 #include "led_strip_encoder.h"
 
 static const char *TAG = "led_encoder";
 
 typedef struct {
     rmt_encoder_t base;
     rmt_encoder_t *bytes_encoder;
     rmt_encoder_t *copy_encoder;
     int state;
     rmt_symbol_word_t reset_code;
 } rmt_led_strip_encoder_t;
 
 static size_t rmt_encode_led_strip(rmt_encoder_t *encoder, rmt_channel_handle_t channel, const void *primary_data, size_t data_size, rmt_encode_state_t *ret_state)
 {
     rmt_led_strip_encoder_t *led_encoder = __containerof(encoder, rmt_led_strip_encoder_t, base);
     rmt_encoder_handle_t bytes_encoder = led_encoder->bytes_encoder;
     rmt_encoder_handle_t copy_encoder = led_encoder->copy_encoder;
     rmt_encode_state_t session_state = RMT_ENCODING_RESET;
     rmt_encode_state_t state = RMT_ENCODING_RESET;
     size_t encoded_symbols = 0;
     switch (led_encoder->state) {
     case 0: // send RGB data
         encoded_symbols += bytes_encoder->encode(bytes_encoder, channel, primary_data, data_size, &session_state);
         if (session_state & RMT_ENCODING_COMPLETE) {
             led_encoder->state = 1; // switch to next state when current encoding session finished
         }
         if (session_state & RMT_ENCODING_MEM_FULL) {
             state |= RMT_ENCODING_MEM_FULL;
             goto out; // yield if there's no free space for encoding artifacts
         }
     // fall-through
     case 1: // send reset code
         encoded_symbols += copy_encoder->encode(copy_encoder, channel, &led_encoder->reset_code,
                                                 sizeof(led_encoder->reset_code), &session_state);
         if (session_state & RMT_ENCODING_COMPLETE) {
             led_encoder->state = RMT_ENCODING_RESET; // back to the initial encoding session
             state |= RMT_ENCODING_COMPLETE;
         }
         if (session_state & RMT_ENCODING_MEM_FULL) {
             state |= RMT_ENCODING_MEM_FULL;
             goto out; // yield if there's no free space for encoding artifacts
         }
     }
 out:
     *ret_state = state;
     return encoded_symbols;
 }
 
 static esp_err_t rmt_del_led_strip_encoder(rmt_encoder_t *encoder)
 {
     rmt_led_strip_encoder_t *led_encoder = __containerof(encoder, rmt_led_strip_encoder_t, base);
     rmt_del_encoder(led_encoder->bytes_encoder);
     rmt_del_encoder(led_encoder->copy_encoder);
     free(led_encoder);
     return ESP_OK;
 }
 
 static esp_err_t rmt_led_strip_encoder_reset(rmt_encoder_t *encoder)
 {
     rmt_led_strip_encoder_t *led_encoder = __containerof(encoder, rmt_led_strip_encoder_t, base);
     rmt_encoder_reset(led_encoder->bytes_encoder);
     rmt_encoder_reset(led_encoder->copy_encoder);
     led_encoder->state = RMT_ENCODING_RESET;
     return ESP_OK;
 }
 
 esp_err_t rmt_new_led_strip_encoder(const led_strip_encoder_config_t *config, rmt_encoder_handle_t *ret_encoder)
 {
     esp_err_t ret = ESP_OK;
     rmt_led_strip_encoder_t *led_encoder = NULL;
     ESP_GOTO_ON_FALSE(config && ret_encoder, ESP_ERR_INVALID_ARG, err, TAG, "invalid argument");
     led_encoder = rmt_alloc_encoder_mem(sizeof(rmt_led_strip_encoder_t));
     ESP_GOTO_ON_FALSE(led_encoder, ESP_ERR_NO_MEM, err, TAG, "no mem for led strip encoder");
     led_encoder->base.encode = rmt_encode_led_strip;
     led_encoder->base.del = rmt_del_led_strip_encoder;
     led_encoder->base.reset = rmt_led_strip_encoder_reset;
     // different led strip might have its own timing requirements, following parameter is for WS2812
     rmt_bytes_encoder_config_t bytes_encoder_config = {
         .bit0 = {
             .level0 = 1,
             .duration0 = 0.3 * config->resolution / 1000000, // T0H=0.3us
             .level1 = 0,
             .duration1 = 0.9 * config->resolution / 1000000, // T0L=0.9us
         },
         .bit1 = {
             .level0 = 1,
             .duration0 = 0.9 * config->resolution / 1000000, // T1H=0.9us
             .level1 = 0,
             .duration1 = 0.3 * config->resolution / 1000000, // T1L=0.3us
         },
         .flags.msb_first = 1 // WS2812 transfer bit order: G7...G0R7...R0B7...B0
     };
     ESP_GOTO_ON_ERROR(rmt_new_bytes_encoder(&bytes_encoder_config, &led_encoder->bytes_encoder), err, TAG, "create bytes encoder failed");
     rmt_copy_encoder_config_t copy_encoder_config = {};
     ESP_GOTO_ON_ERROR(rmt_new_copy_encoder(&copy_encoder_config, &led_encoder->copy_encoder), err, TAG, "create copy encoder failed");
 
     uint32_t reset_ticks = config->resolution / 1000000 * 50 / 2; // reset code duration defaults to 50us
     led_encoder->reset_code = (rmt_symbol_word_t) {
         .level0 = 0,
         .duration0 = reset_ticks,
         .level1 = 0,
         .duration1 = reset_ticks,
     };
     *ret_encoder = &led_encoder->base;
     return ESP_OK;
 err:
     if (led_encoder) {
         if (led_encoder->bytes_encoder) {
             rmt_del_encoder(led_encoder->bytes_encoder);
         }
         if (led_encoder->copy_encoder) {
             rmt_del_encoder(led_encoder->copy_encoder);
         }
         free(led_encoder);
     }
     return ret;
 }

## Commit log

2025-09-10 invertir motores DC
2025-09-10 programacion de movimiento
2025-09-12 programacion de comportamiento
2025-09-14 mejoras config
    [RearFrameLeftModV2.stl, RearFrameRightModV2.stl, TestN20.stl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]
2025-09-16 refactor web app y fixes record
    [ProgramManager.cpp]
2025-09-17 Grabacion con bluetooth y luz de grabacion
2025-09-17 fix stop program gamepad
    [ProgramManager.cpp, gamepadHandler.cpp, sketch.cpp]
2026-05-25 mejoras app y actualizacion esp-idf 5.5.4
    [partitions.csv]
2026-05-25 OTA y 8MB Flash
    [partitions.csv]
2026-05-28 Fase 1: eliminar dependencias de arduino y bluepad32_arduino
    - Reemplaza Arduino Preferences con NvsPrefs (wrapper ESP-IDF NVS nativo)
    - Reemplaza GamepadPtr/BP32 con GamepadData struct + bp32_platform.cpp (custom uni_platform_t)
    - Reemplaza pinMode/digitalWrite con gpio_set_direction/gpio_set_level en actuators.cpp
    - Reemplaza millis() con esp_timer_get_time() en ledStripHandler y ProgramManager
    - Reemplaza ESPmDNS con mdns.h nativo en webServerHandler
    - Reemplaza DNSServer con dns_server.c (servidor UDP mínimo para captive portal)
    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
2026-05-28 Fase 2: reemplazar bluepad32+btstack por esp_hid_host nativo
    - Elimina components/bluepad32, bluepad32_arduino, btstack y arduino (~99 MB)
    - Nuevo hid_gamepad.cpp: inicializa Bluedroid + esp_hidh, escaneo BLE/BT,
    parser HID para Xbox Series X/S y gamepad genérico estándar
    - Copia esp_hid_gap.{h,c} del ejemplo oficial de IDF (BT controller init +
    GAP scanning para BLE y BR/EDR)
    - main.c simplificado: solo lanza app_task_start(), sin btstack run loop
    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
2026-05-28 Fase 3: reemplaza iot_servo por LEDC directo, elimina componentes locales sin uso
    - actuators.cpp: reemplaza espressif/servo (iot_servo_init/write_angle) con
    LEDC directo (ledc_timer_config + ledc_channel_config + servo_write_angle)
    - idf_component.yml: elimina espressif/servo de las dependencias gestionadas
    - CMakeLists.txt: renombra proyecto de bluepad32_arduino_app_template a esprc_brain
    - Elimina components/cmd_nvs, cmd_nvs_4.4, cmd_system, cmd_system_4.4
    (ninguno referenciado por main; residuo del template original)
2026-05-28 fix(c6): compila hid_gamepad solo en esp32, stub no-op para otros targets
    esp_hid_gap.c usa esp_ble_gap_set_scan_params/start_scanning que no existen
    en esp32c6 (BLE-only, controller diferente). Solución:
    - CMakeLists: incluye hid_gamepad.cpp + esp_hid_gap.c solo con CONFIG_IDF_TARGET_ESP32
    - hid_gamepad_stub.cpp: implementaciones vacías para targets sin Classic BT
    - sdkconfig.defaults.esp32c6: desactiva BT_HID_HOST_ENABLED (feature Classic BT)
2026-05-28 fix(c6): nvs_flash_init antes de usar NVS/WiFi, tskNO_AFFINITY para single-core
    - nvs_flash_init() faltaba en main_task: el framework Arduino lo llamaba
    automáticamente; ahora se llama explícitamente con manejo de erase si
    NVS_NO_FREE_PAGES o NVS_NEW_VERSION_FOUND
    - xTaskCreatePinnedToCore(..., 1) crasheaba en C6 (single-core, core 1 no existe);
    reemplazado por tskNO_AFFINITY
    [sketch.cpp]
2026-05-29 docs: actualiza README y CLAUDE.md para pure ESP-IDF
    - README (ES/EN): reemplaza referencias a Bluepad32/Arduino por esp_hid_host
    nativo; aclara controllers soportados (Xbox S/X + HID genérico, solo ESP32);
    quita --recursive del clone; actualiza estructura de carpetas y licencia
    - CLAUDE.md: nueva tabla de dependencias gestionadas; sección BT actualizada;
    tabla de módulos con archivos nuevos (hid_gamepad, esp_hid_gap, nvs_prefs,
    dns_server, stub); OTA menciona esprc_brain.bin; remove referencias a Arduino
2026-05-29 chore: elimina patches/ obsoleto y limpia comentarios de bluepad32/btstack
    - Firmware/patches/: era para integrar bluepad32 con Arduino main.cpp; eliminado
    - gamepad_types.h, gamepadHandler.cpp, sketch.cpp: 3 comentarios que referenciaban
    bluepad32/btstack/bp32 actualizados
2026-05-29 feat(c6): habilita BLE HID en esp32c6 para gamepad Xbox Series X/S
    - sdkconfig.defaults.esp32c6: agrega CONFIG_BT_BLE_ENABLED=y y
    CONFIG_BT_BLE_42_FEATURES_SUPPORTED=y
    - esp_hid_gap.h: agrega #include "sdkconfig.h" para que CONFIG_BT_BLE_ENABLED
    se evalúe correctamente al incluir el header (sin él, HID_HOST_MODE=0 IDLE)
    - CMakeLists.txt: mueve bt+esp_hid a REQUIRES incondicional; REQUIRES dinámico
    en if() no propaga include paths en IDF CMake
    En C6: HID_HOST_MODE=HIDH_BLE_MODE(1), BLE scan activo, Xbox via BLE HID.
    En ESP32: HID_HOST_MODE=HIDH_BTDM_MODE(3), Classic BT + BLE.
2026-05-29 fix: mapeo completo de botones Xbox Series X/S BLE confirmado desde datos reales
    Layout del reporte HID (16 bytes, report ID stripped por esp_hidh):
    - Bytes 0-7: sticks (uint16 LE, centro=32767): LSx LSy RSx RSy
    - Bytes 8-9: LT (0-1023)
    - Bytes 10-11: RT (0-1023)
    - Bytes 12-13: BTN+HAT — A=bit8 B=bit9 X=bit11 Y=bit12 LB=bit14 RB=bit15
    HAT bits3:0 (0=no,1=N,3=E,5=S,7=W)
    - Byte 14: View=bit2 Menu=bit3 LS=bit5 RS=bit6
    - Byte 15: Capture=bit0
    También: log "Motor speed:" bajado a LOGD para no saturar el monitor
    [actuators.cpp]
2026-05-29 docs: actualiza BT — C6 soporta Xbox vía BLE, layout HID confirmado
    - README/EN: C6 ya soporta Xbox Series X/S vía BLE (elimina restricción ESP32-only)
    - CLAUDE.md: sección BT reescrita con layout HID completo confirmado desde
    hardware real (A=bit8 B=bit9 X=bit11 Y=bit12 LB=bit14 RB=bit15 + byte14/15),
    notas sobre CMakeLists REQUIRES incondicional y sdkconfig.h en esp_hid_gap.h
2026-06-09 Add pan/tilt camera servo support with webapp control
    Adds hardware pan/tilt servo control via two new LEDC channels (CH3/CH4)
    on both ESP32 and ESP32-C6. The right analog stick of any connected
    gamepad drives the servos with configurable deadzone, saturation, and
    per-axis invert. A third virtual joystick (joy3) in the webapp tab-A
    sends pan/tilt commands over the existing WebSocket action loop.
    Full config UI added to the settings tab: servo type presets (SG90,
    S3003, custom), center position, left/right/up/down limits, and min/max
    pulse-width tuning. All fields persist to NVS and are included in
    config backup/restore. EN + ES translations added.
    Also:
    - OTA file picker replaced with a dr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
    [actuators.cpp, gamepadHandler.cpp, pins.h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]
2026-06-10 Add FPV tab, cam servo hold mode, video recording, WS/BT arbitration, smooth servo interpolation
    Webapp:
    - New FPV tab: full-screen camera stream + drive joystick + invisible pan/tilt
    pad overlay, light/servo controls, record and fullscreen buttons — optimized
    for mobile landscape
    - Camera servo hold mode: stick controls angular velocity instead of absolute
    position; servo maintains position on release. Hold/center buttons on all
    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
2026-06-11 Add configurable GPIO pins, BT gamepad camera buttons, low-latency CamPad
    GPIO pins (motor, servos, LED strip) are now runtime-configurable via NVS
    and the webapp (GET/POST /api/pins + POST /api/pins/reset). pins.h becomes
    compile-time defaults only; VehicleState gains pin* fields loaded at boot.
    First boot after OTA falls back to defaults — no config lost. setupActuators()
    now takes VehicleState*. Backup/restore includes pin keys.
    BT gamepad camera controls: RS click (GAMEPAD_BTN_THUMB_R) centers cam servos;
    Select/View (GAMEPAD_BTN_SELECT, bit10) toggles camHoldMode and persists to NVS.
    Added GAMEPAD_BTN_SELECT to gamepad_types.h.
    CamPad.setSendCallback: throttled 30 ms send on pointer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
    [actuators.cpp, gamepadHandler.cpp, pins.h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]
2026-06-27 brain con ESC+Brushless
2026-06-27 modo crawl ESC
